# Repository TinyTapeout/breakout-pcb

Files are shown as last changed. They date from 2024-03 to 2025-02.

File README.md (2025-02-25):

# Tiny Tapeout breakout PCBs

The Tiny Tapeout chips are delivered on a breakout board that allows:
   
   * the demo board to host and interact with the IC and its projects
   
   * easily moving the ASIC to other more specialized PCBs

The PCBs are keyed such that direction of insertion onto hosts is made clear.

## Repo organization 

Versionning has been refactored such that we only have a single directory, moving forward, which will always be the latest iteration of the breakout board.  Prior versions are tagged and [all available here](https://github.com/TinyTapeout/breakout-pcb/tags).

To facilitate referencing prior boards, renders and schematic PDFs are archived in [docs/historic](docs/historic), and displayed here.

Additionally, there are directories dedicated to socket adapters and "ASIC simulator" FPGA boards.

## TT08 QFN breakout

The [breakout-tt08-qfn](https://github.com/TinyTapeout/breakout-pcb/releases/tag/breakout-tt08) is a QFN breakout suitable for TT06 chips and beyond.  

The ipex/u.fl connectors used for TT06/TT07 were deemed difficult to use for some and led to relatively high capacitance.  This iteration of the breakout replaces these with standard 100mil headers.

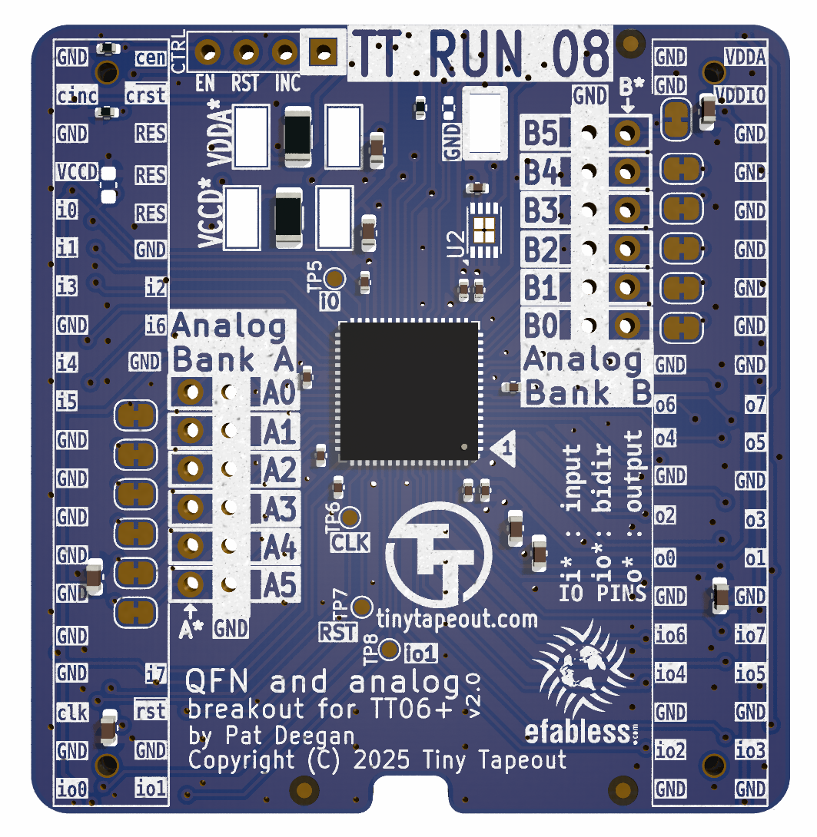
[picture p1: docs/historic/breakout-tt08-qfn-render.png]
TT08 QFN


Each bank of the analog I/O is available through one such connector and also routed to the headers down to the demoboard, but only in order to allow for

  * custom host boards to access these I/O
  
  * pull-downs to ground to avoid floating pins.

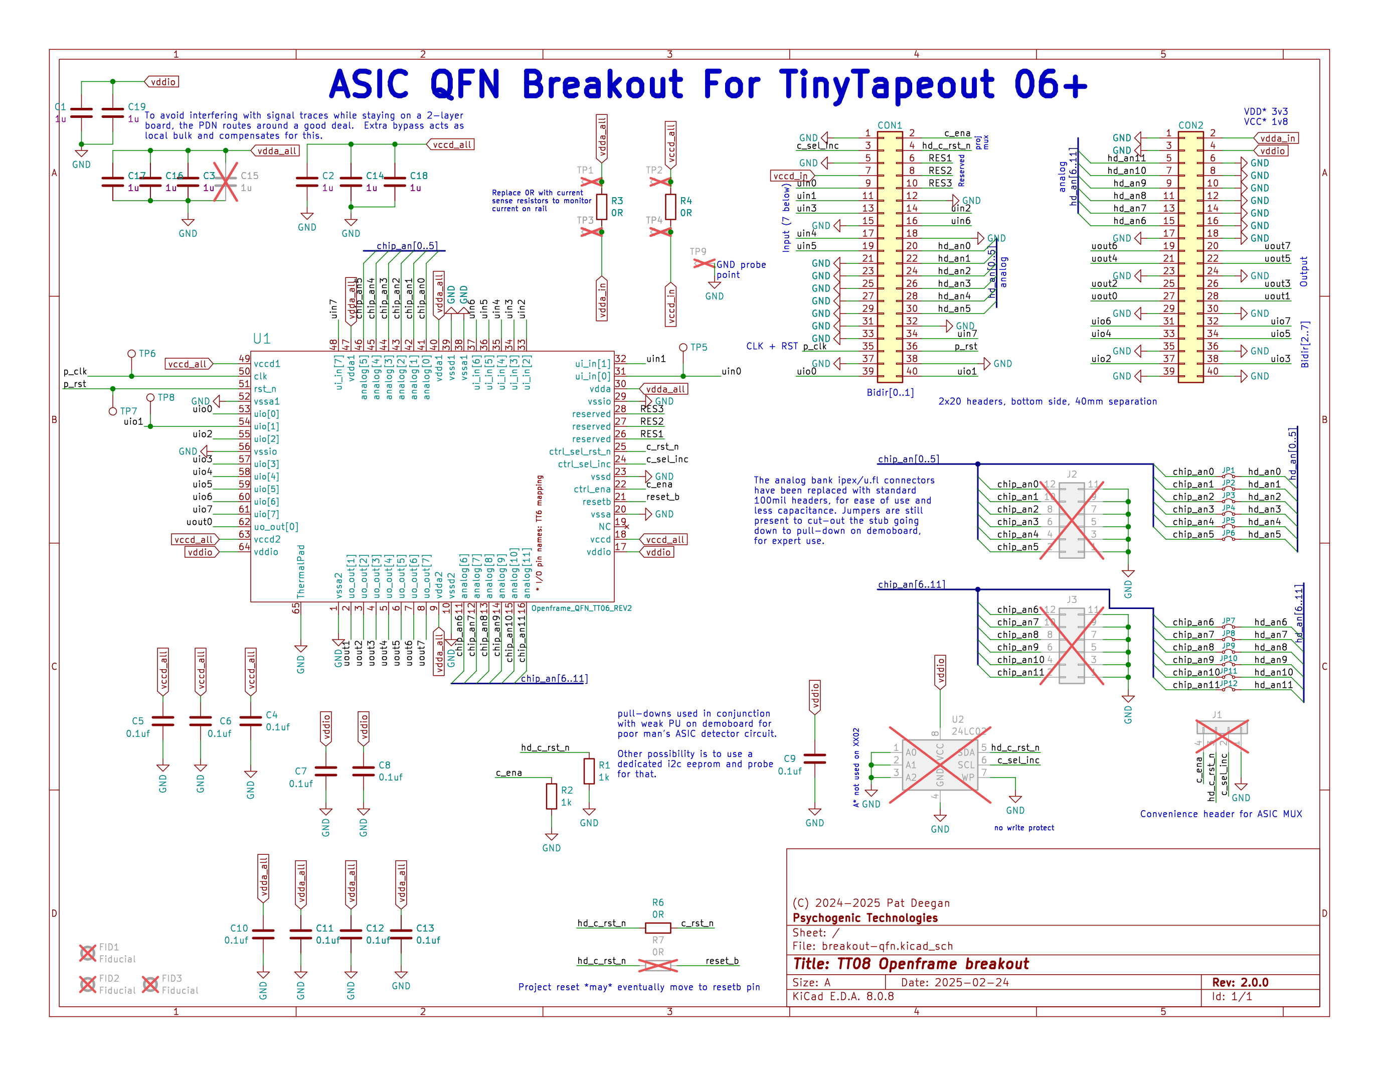
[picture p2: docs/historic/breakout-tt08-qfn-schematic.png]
TT08 breakout schematic


[TT08 breakout schematic PDF](docs/historic/breakout-tt08-qfn.pdf)

## TT07 QFN breakout

The [breakout-tt07-qfn](https://github.com/TinyTapeout/breakout-pcb/releases/tag/breakout-tt07) is a QFN breakout suitable for TT06 chips and beyond.  It was to have only minor changes as compared to the TT06 breakout PCB but, unfortunately, has the ASIC project MUX `reset_n` and `increment` wires crossed and is thus mislabelled.  

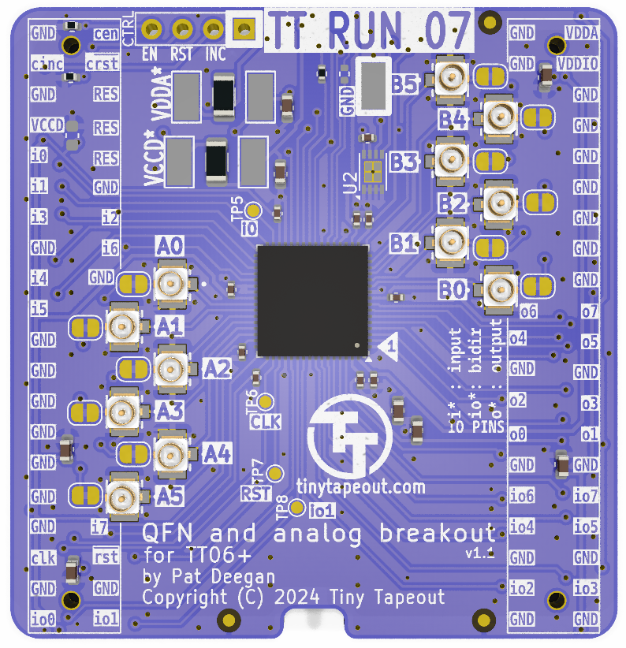
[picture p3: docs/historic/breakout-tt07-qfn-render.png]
TT07 QFN


Analog I/O is available through ipex/u.fl connectors and also routed to the headers and down to the demoboard, but only in order to allow for

  * custom host boards to access these I/O
  
  * pull-downs to ground to avoid floating pins.

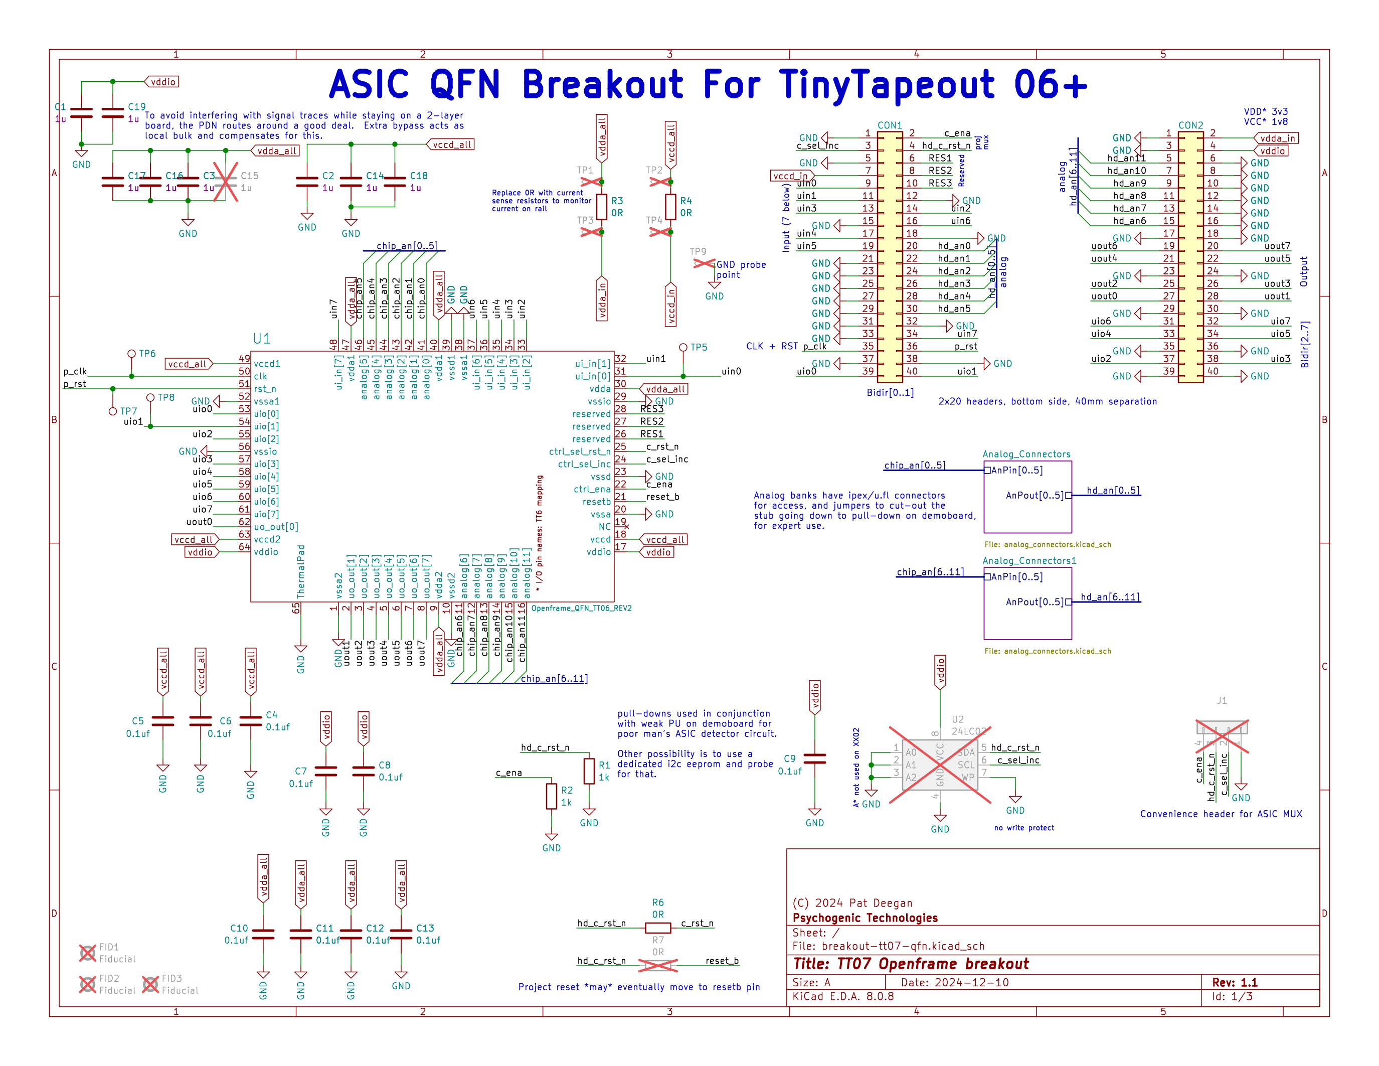
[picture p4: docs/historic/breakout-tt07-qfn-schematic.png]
TT07 breakout schematic


[TT07 breakout schematic PDF](docs/historic/breakout-tt07-qfn.pdf)

## TT06 QFN breakout

The [breakout-tt06-qfn](https://github.com/TinyTapeout/breakout-pcb/releases/tag/breakout-tt06) is a QFN breakout suitable for TT06 chips and beyond.  With TT06 came support for analog and mixed signal projects, as well as a new pinout for the QFN to support this and the on-board project MUX.  These breaking changes are reflected in a new, wider, footprint that sidesteps the possibility of placing incompatible prior breakouts on the demoboard.

Sensitive analog I/O is available through ipex/u.fl connectors.

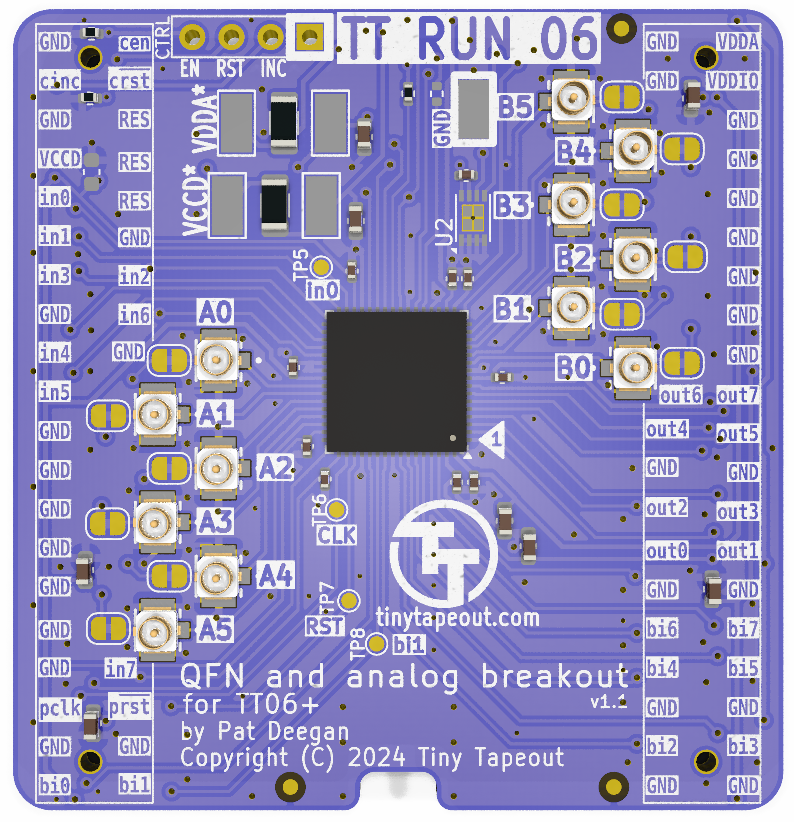
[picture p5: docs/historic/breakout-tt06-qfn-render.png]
TT06 QFN


The analog I/O is also routed to the headers and down to the demoboard, but only in order to allow for

  * custom host boards to access these I/O
  
  * pull-downs to ground to avoid floating pins.
  
Unfortunately, the production run for those demo boards had very low valued resistances which, if you wish to interact with analog projects, had to be removed or replaced (see the errata on the [demoboard documentation](https://github.com/TinyTapeout/tt-demo-pcb/tree/tt06) for details).

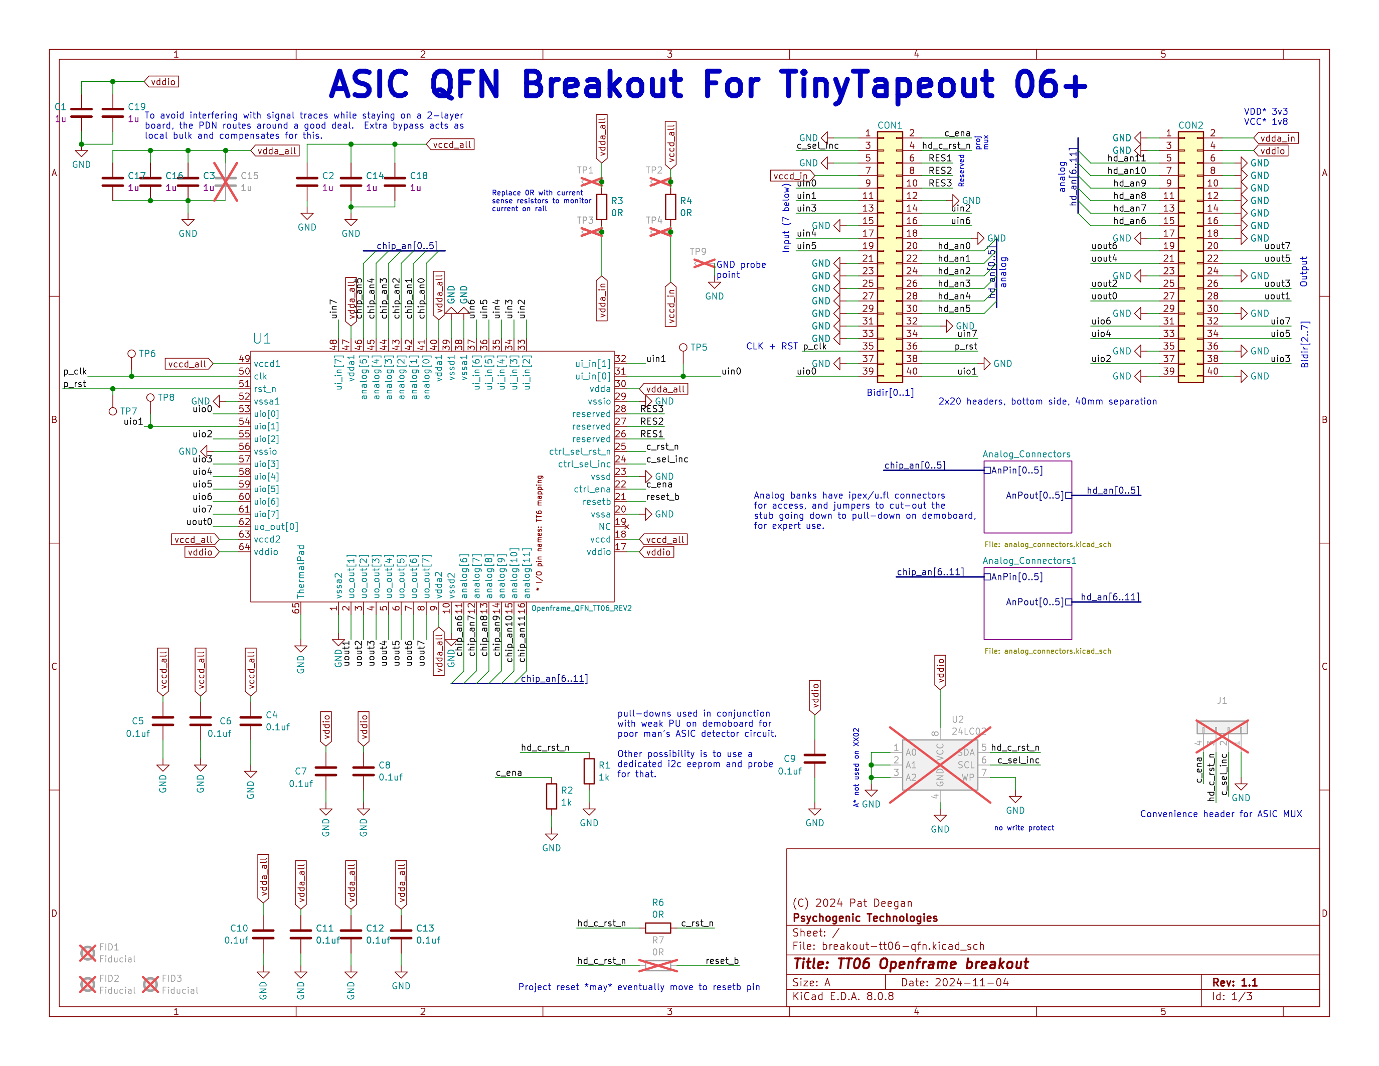
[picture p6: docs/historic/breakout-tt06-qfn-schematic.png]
TT06 breakout schematic


[TT06 breakout schematic PDF](docs/historic/breakout-tt06-qfn.pdf)

## TT04/TT05 QFN breakout

The [breakout-tt04-qfn](https://github.com/TinyTapeout/breakout-pcb/releases/tag/breakout-tt04) is a QFN breakout suitable for TT04 and TT05 chips.  This breakout, with some differences in silk screen, was used for the TT03p5 trial run, as well as TT04 and TT05.

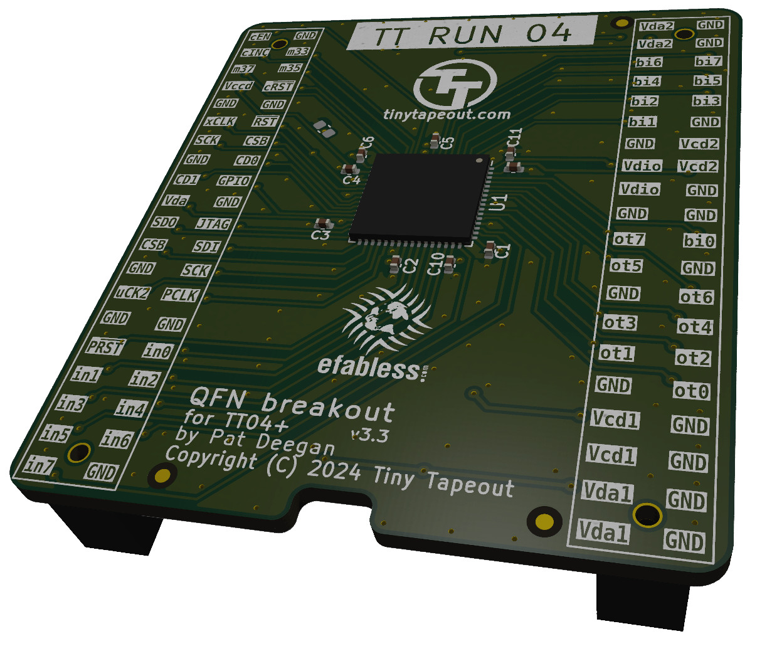
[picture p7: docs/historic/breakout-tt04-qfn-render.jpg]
TT04 QFN


This PCB moved to more easily sourced standard 100 mil pin headers, placed on the bottom of the PCB.  Markings on top are Tiny Tapeout names of the pins (in0 is input 0, ot5 is output 5, etc).

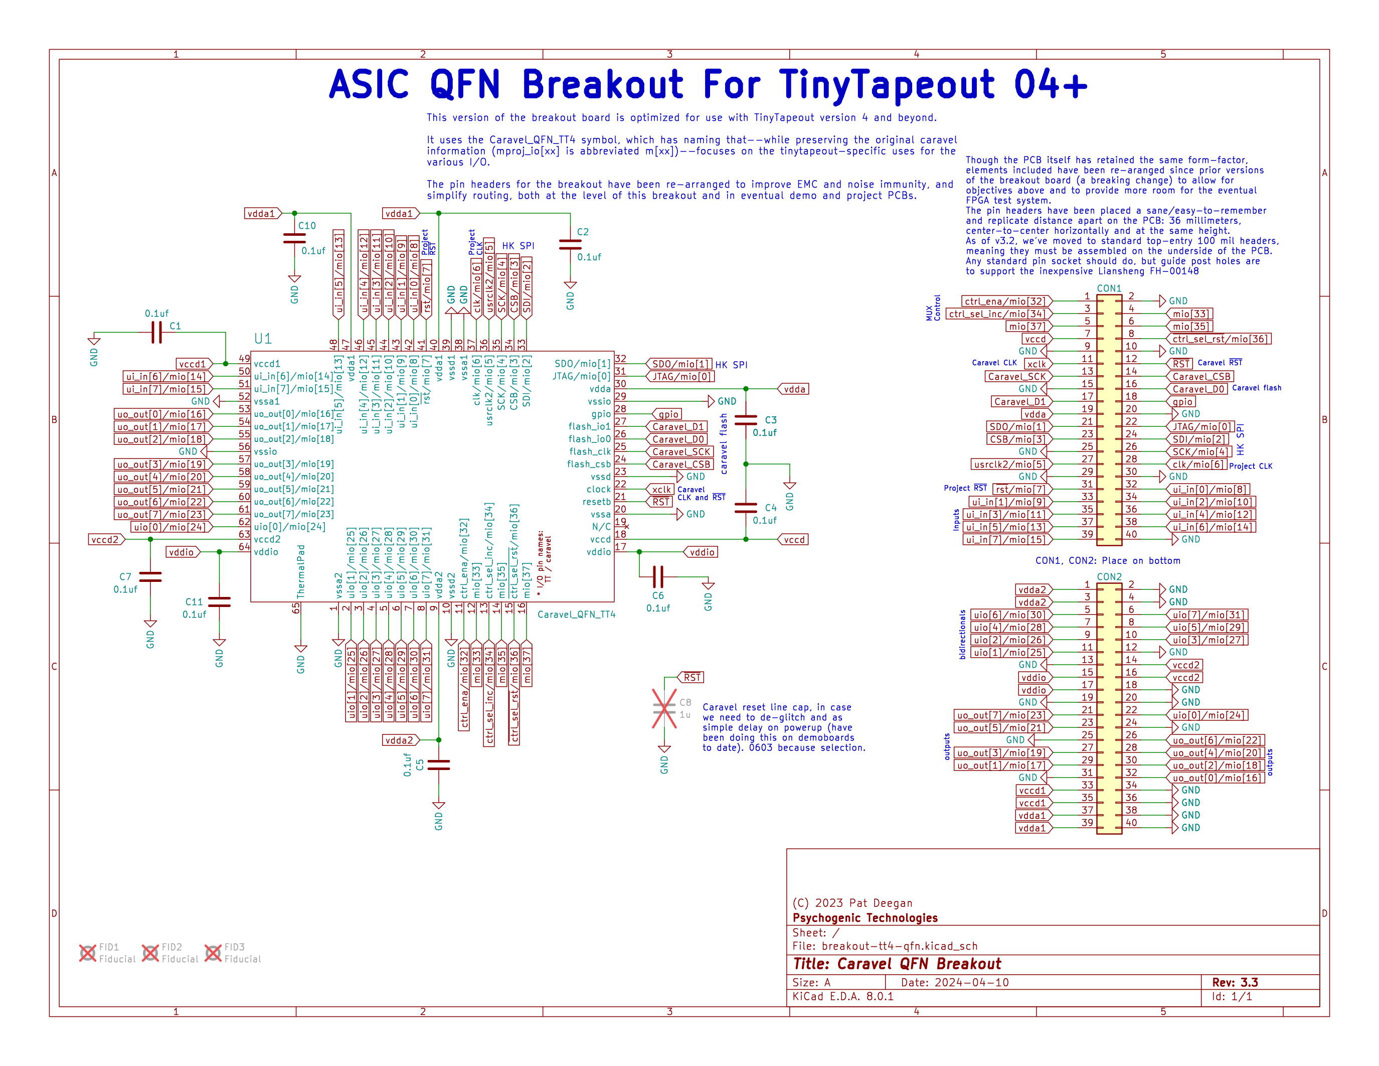
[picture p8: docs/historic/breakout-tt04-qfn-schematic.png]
TT04 breakout schematic


[TT04 breakout schematic PDF](docs/historic/breakout-tt04-qfn.pdf)

## TT03 QFN breakout

The [breakout-tt03-qfn](https://github.com/TinyTapeout/breakout-pcb/releases/tag/breakout-tt03) holds a QFN breakout suitable for TT02 and TT03 chips.

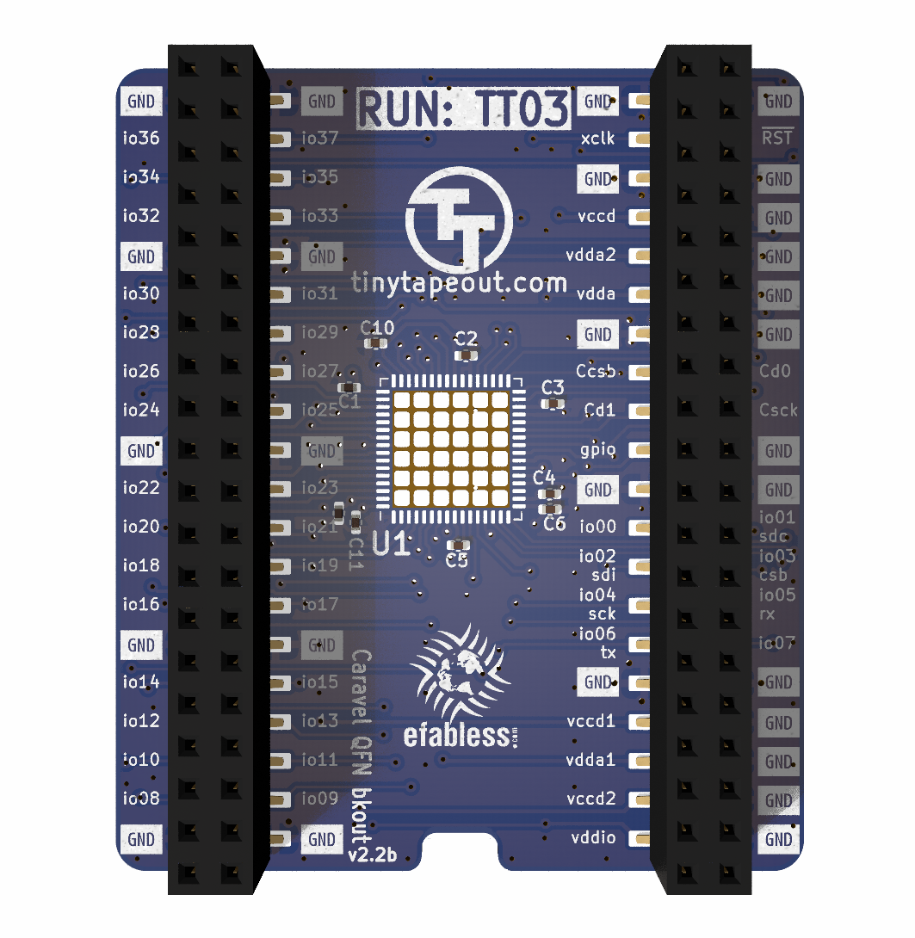
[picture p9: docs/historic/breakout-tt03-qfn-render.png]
TT03 QFN


It provides access to the project inputs, outputs, select pins etc, though the naming on the PCB refers to the caravel mprj_io pin numbers.

The pin headers used up to this point have been dual entry (access from both top and bottom).

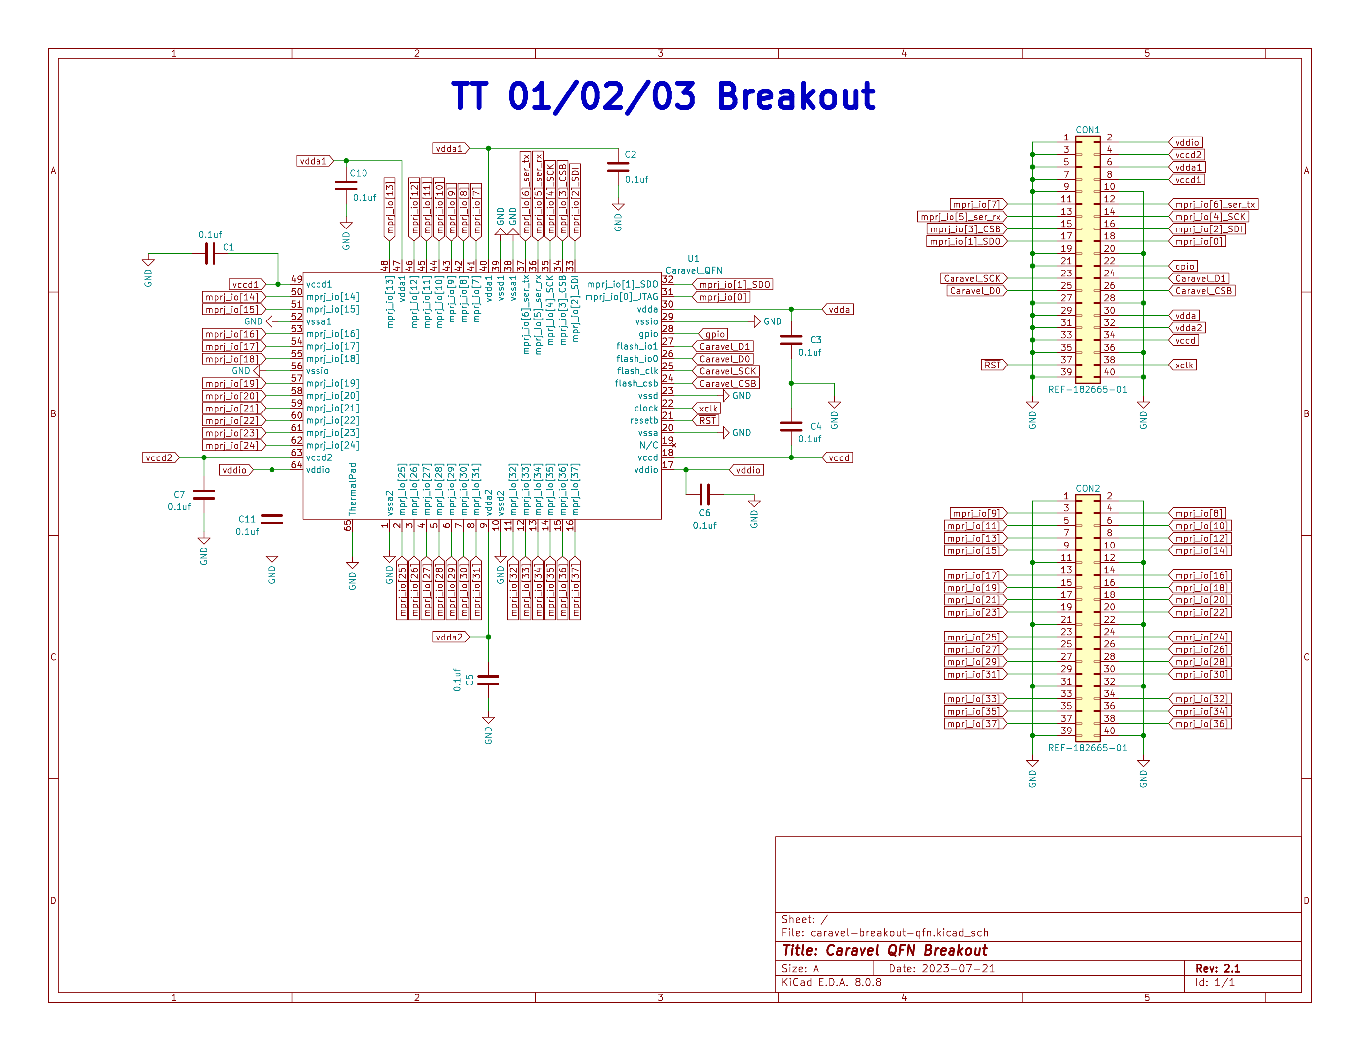
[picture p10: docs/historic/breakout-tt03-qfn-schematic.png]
TT03 breakout schematic


[TT03 breakout schematic PDF](docs/historic/breakout-tt03-qfn.pdf)

## FPGA ASIC simulation PCBs

Following the same footprints as the breakout boards, the ASIC simulation PCBs are circuits designed to allow for use of demo or custom boards while developing or awaiting the actual chips.  A version was already produced for TT03 and a TT04-compatible version, with the extra I/O and dedicated clock/reset pins, is under development.

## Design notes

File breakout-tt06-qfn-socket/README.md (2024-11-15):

# Tiny Tapeout QFN64 socket adapter (TT06+)

For testing Tiny Tapeout chips not yet soldered to a breakout board.<br />
Based on the [TT06 QFN breakout board](https://github.com/TinyTapeout/breakout-pcb) by Pat Deegan.

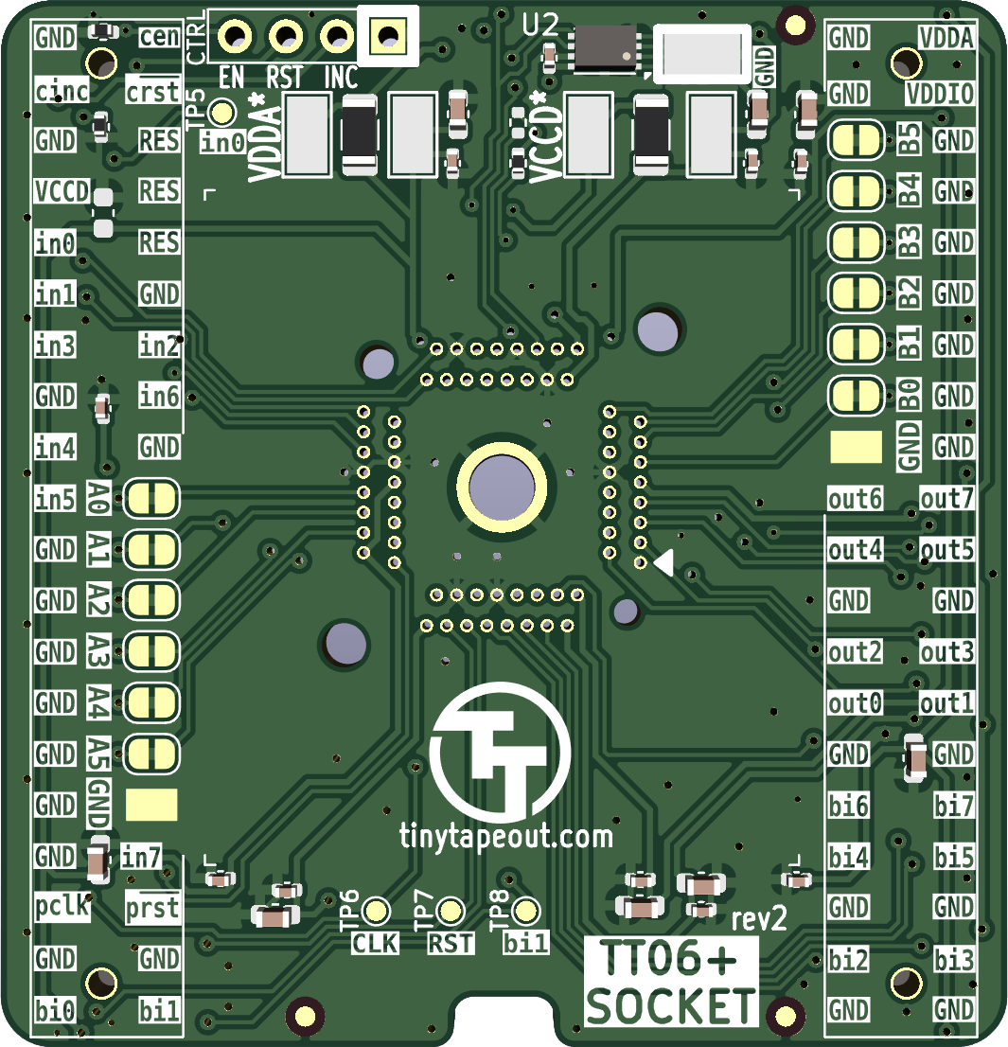
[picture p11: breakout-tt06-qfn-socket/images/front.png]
&emsp;
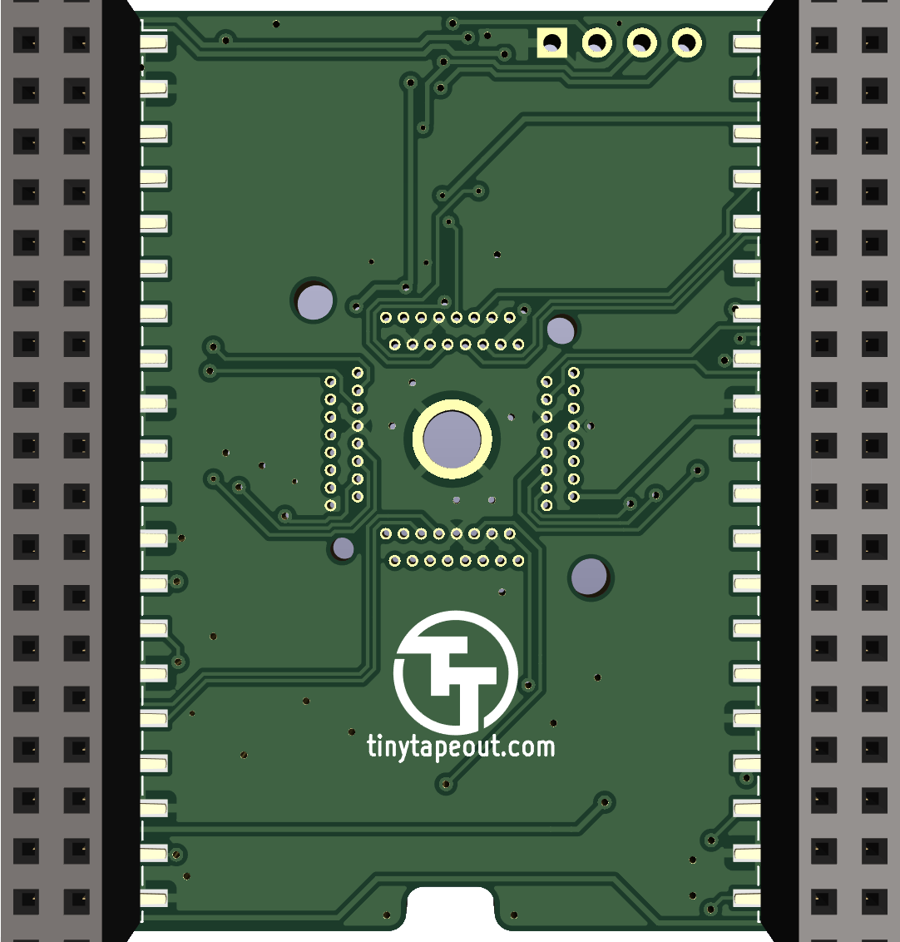
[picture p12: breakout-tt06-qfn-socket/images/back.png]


To be used with [Enplas QFN-64BT-0.5-01](https://www.waveshare.com/qfn-64bt-0.5-01.htm) sockets.

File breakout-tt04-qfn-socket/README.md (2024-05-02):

# Tiny Tapeout QFN64 socket adapter (TT04+)

For testing Tiny Tapeout chips not yet soldered to a breakout board.<br />
Based on the [TT04 QFN breakout board](https://github.com/TinyTapeout/breakout-pcb) by Pat Deegan.

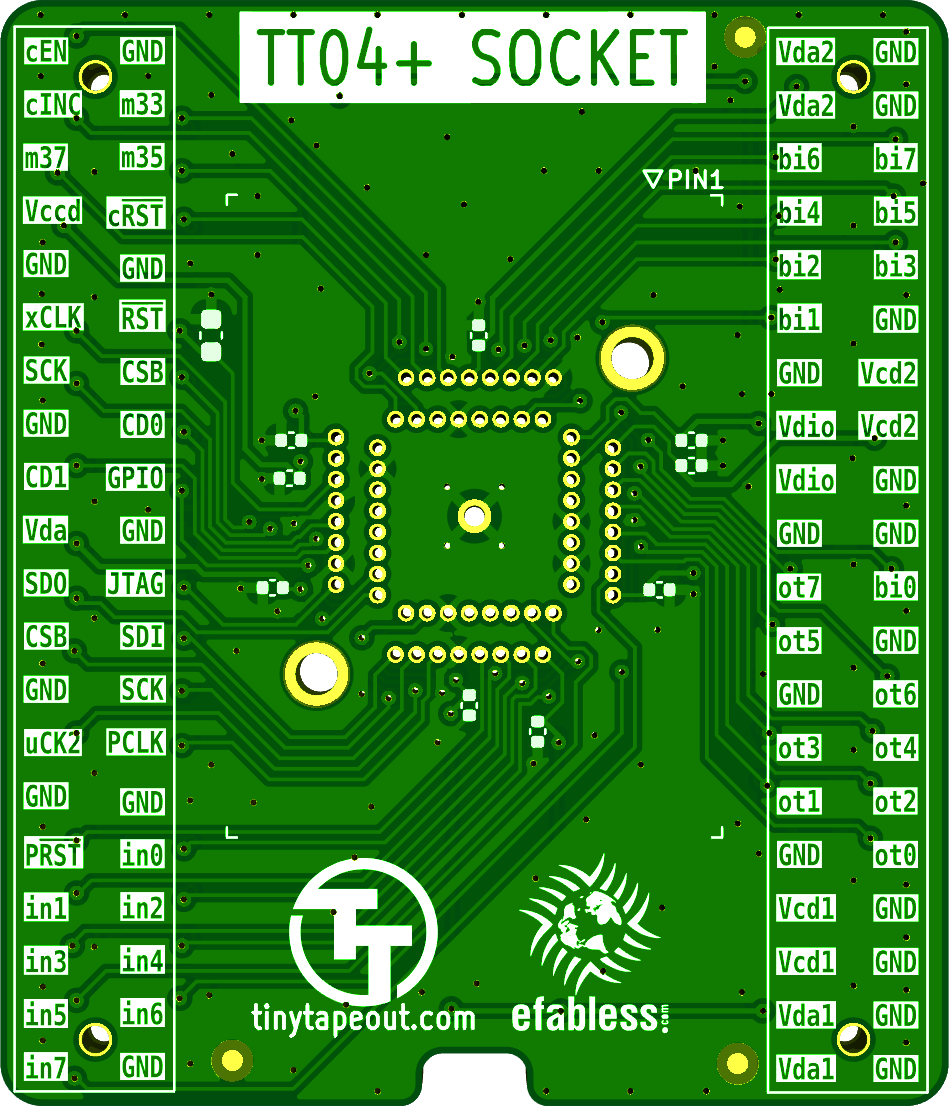
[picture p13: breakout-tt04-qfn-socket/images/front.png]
&emsp;
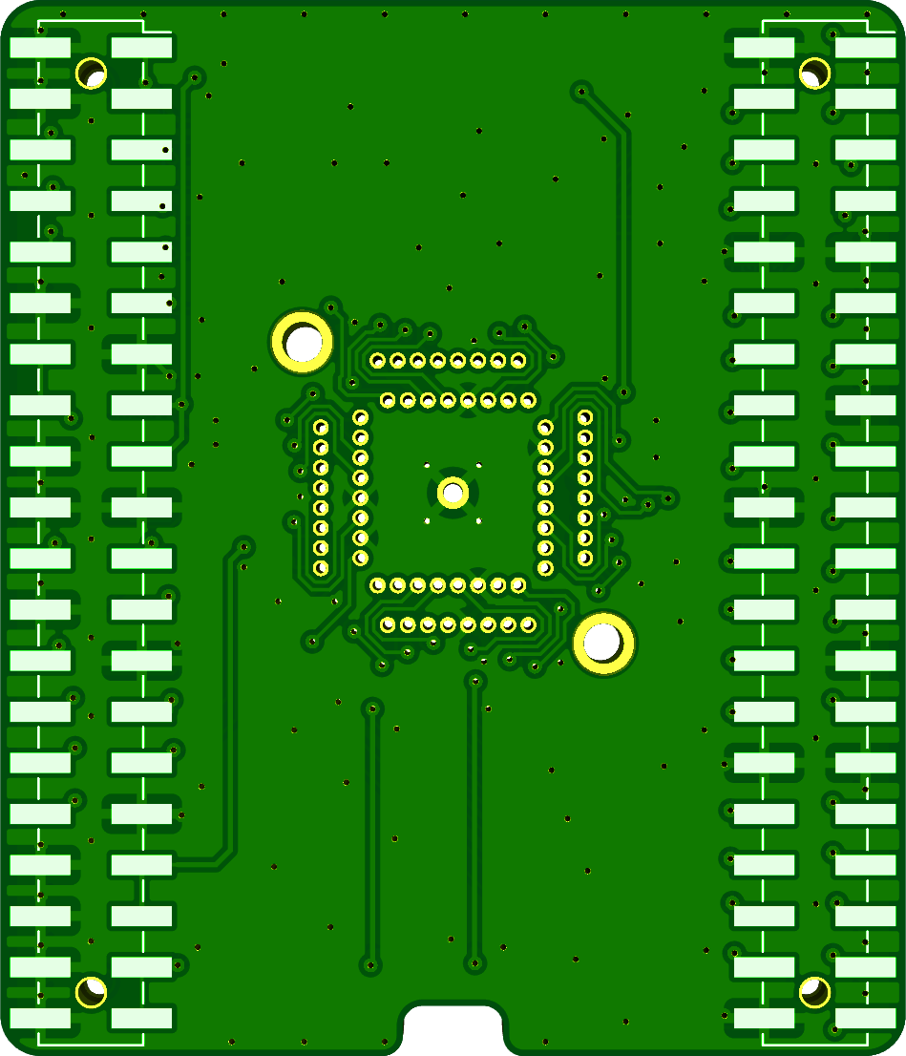
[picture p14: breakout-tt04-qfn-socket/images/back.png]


To be used with Chinese 9x9-64-0.5 QFN sockets, such as those available with these vendors:
[#1](https://www.aliexpress.com/item/1005005700155525.html) /
[#2](https://www.taobao.com/list/item/708110757161.htm) /
[#3](https://www.taobao.com/list/item/736773077075.htm)

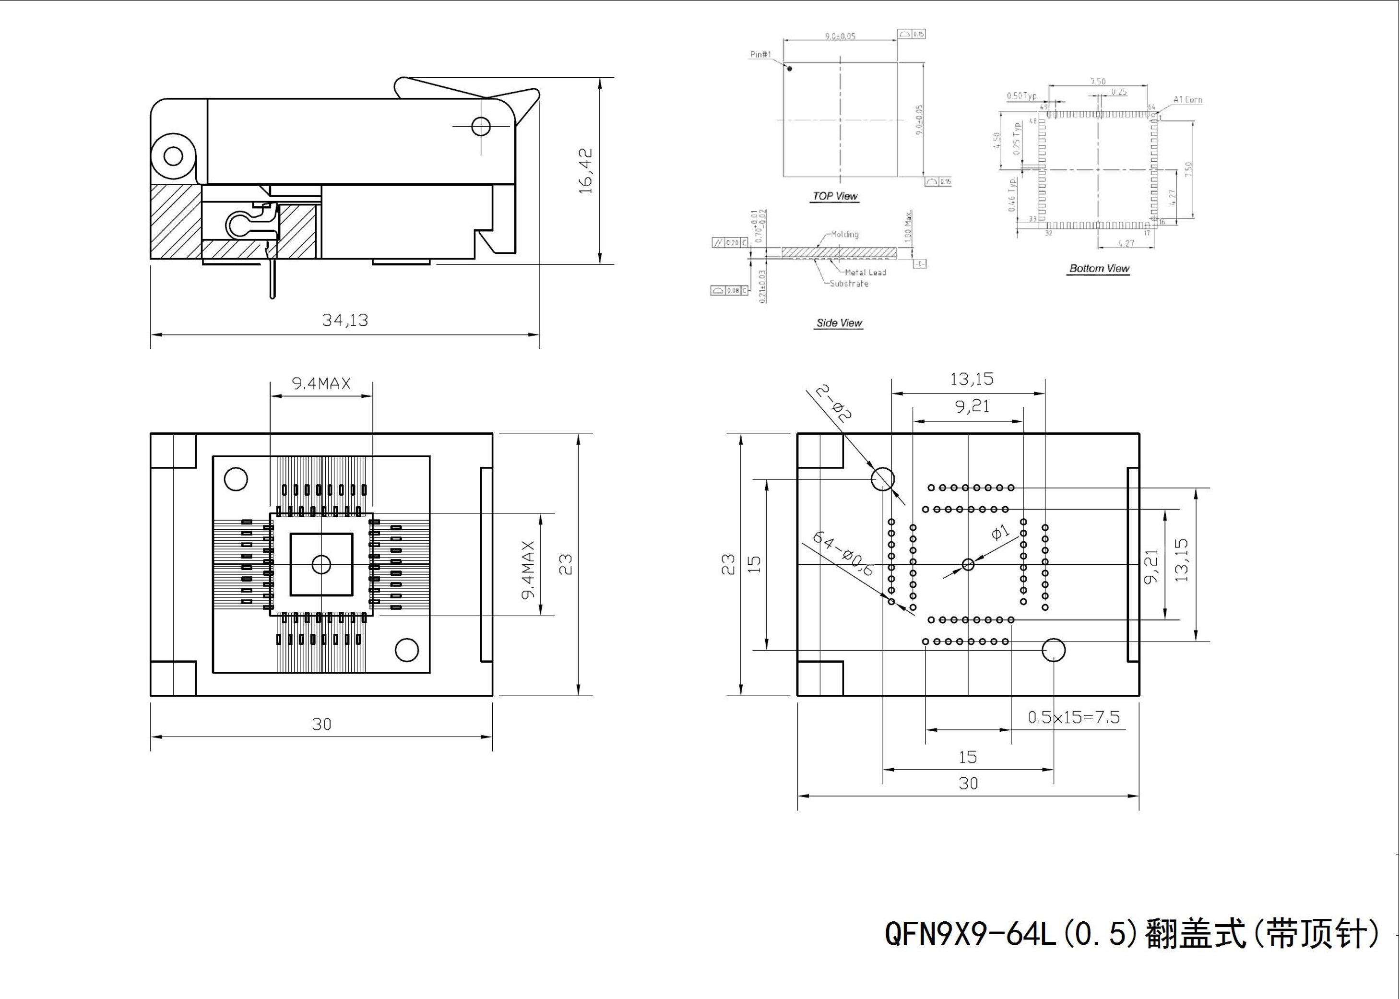
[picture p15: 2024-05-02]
breakout-tt04-qfn-socket/images/footprint.jpg

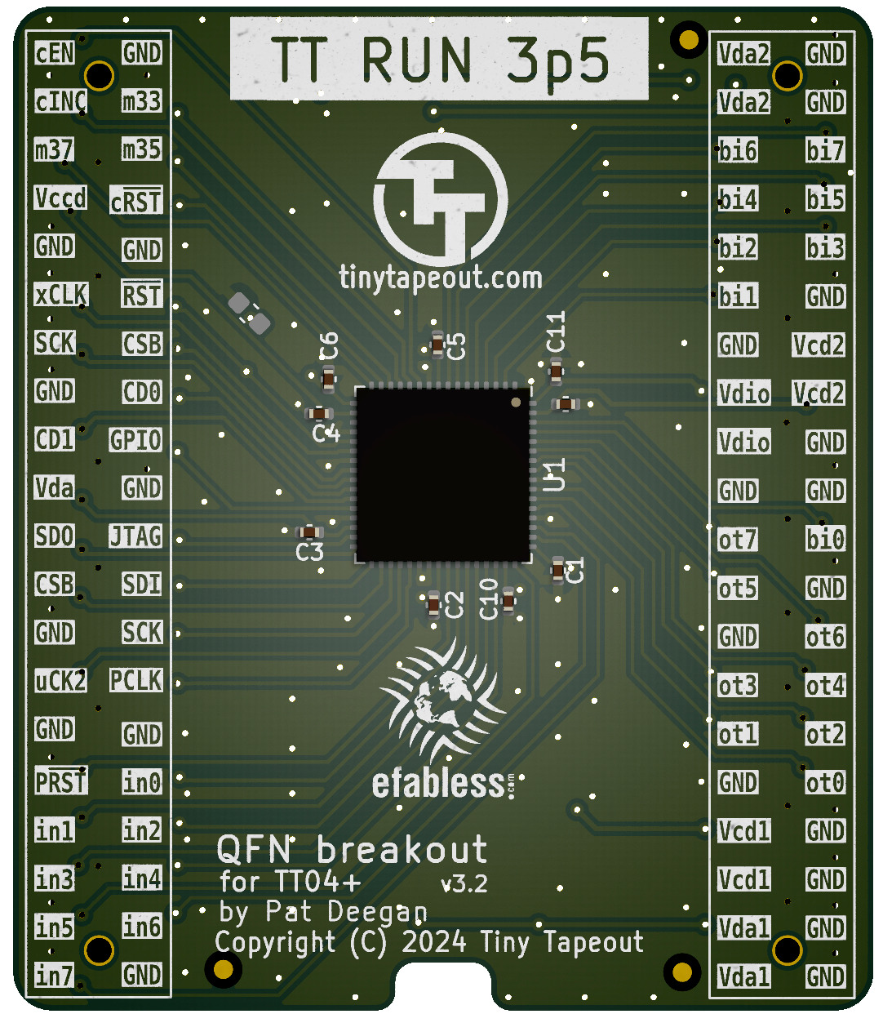
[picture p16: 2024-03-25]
images/tt04-breakout.jpg

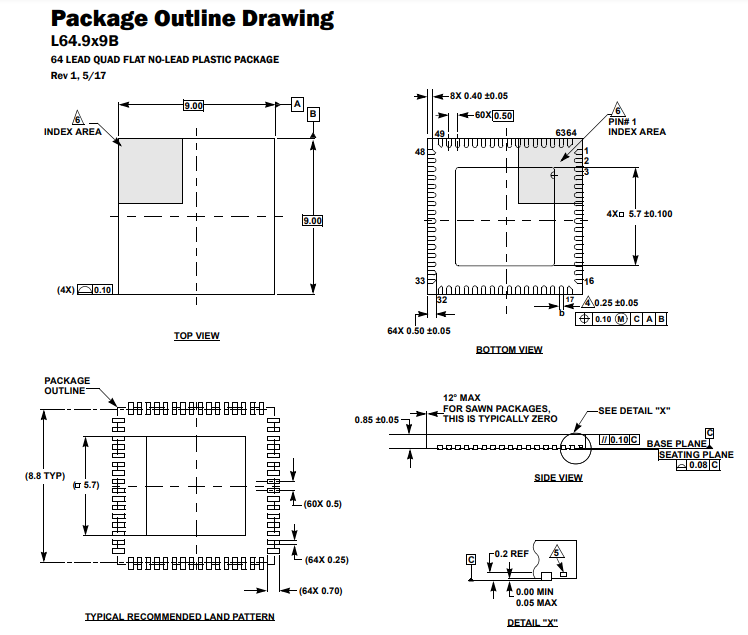
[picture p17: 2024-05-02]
breakout-tt04-qfn-socket/images/package.jpg

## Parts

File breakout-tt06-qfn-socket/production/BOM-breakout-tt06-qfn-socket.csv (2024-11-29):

Comment | Designator | Footprint | LCSC | Quantity
1k | R1,R2 | R_0402_1005Metric | C11702 | 2
0.1u | C10,C11,C12,C13,C4,C5,C6,C7,C8,C9 | C_0402_1005Metric | C1525 | 10
1u | C1,C14,C15,C16,C17,C18,C19,C2,C3 | C_0603_1608Metric | C15849 | 9
0R | R6 | R_0402_1005Metric | C17168 | 1
0R | R3,R4 | R_1206_3216Metric | C17888 | 2
~ | CON1,CON2 | FH-00148_PinSocket_2x20_P2.54mm | C2685092 | 2
TestPoint_Alt | TP1,TP2,TP3,TP4,TP9 | TestPoint_Keystone_5019_Minature | C5199800 | 5
Enplas QFN-64BT-0.5-01 | U1 | Socket-QFN-64-1EP_9x9mm_P0.5mm_rot90 |  | 1

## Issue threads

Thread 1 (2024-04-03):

Link at the back of tt04 PCB sends you to the old repo

urish, 2024-04-03:
It reads: github.com/TinyTapeout/caravel-breakout-pcb
Should be: github.com/TinyTapeout/breakout-pcb (this repo)

psychogenic, 2024-04-11:
Created new v3.3 release of TT04 carriers, updated silk with this fix.

Closed 2024-04-11.

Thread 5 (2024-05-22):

make the pin 1 marker much more obvious

mattvenn, 2024-05-22:

urish, 2024-05-22:
Is this for TT05? or later

mattvenn, 2024-05-22:
All boards in use and in future. A tiny dot or similar isn't clear enough

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

urish, 2024-05-22:
@psychogenic can you make this change and include it in the gerber files for TT05 carrier boards?

psychogenic, 2024-06-04:
Gave it le fat arrow, think it'll be plenty clear
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

urish, 2024-06-04:
Thanks! maybe even write "1" or "Pin 1" on top, to be super duper clear?

psychogenic, 2024-06-04:
Is it worth it?  Feels like anyone doing PCBA with a QFN can probably handle the hint.  But I'll do it if ya like.

psychogenic, 2024-06-04:
Ok, this would be hard to miss then
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

urish, 2024-06-05:
Beauty!

Closed 2024-06-05.

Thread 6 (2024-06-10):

make pin1 marker for the black qfn breakout

mattvenn, 2024-06-10:
Proppy in the discord just soldered it the wrong way round.

urish, 2024-06-10:
Similar to #5

mattvenn, 2024-06-11:
yeah. all boards should have a massive pin 1 marker

psychogenic, 2024-06-11:
Done and will do for future, sent to the Stu
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

Closed 2024-06-11.

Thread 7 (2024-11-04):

TT06 breakout: c_sel_inc and c_rst_n pins swapped

urish, 2024-11-04:
There's an error in the schematic - the pins are swapped:

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

The symbol pinout is correct, but the wire labels are wrong: `c_sel_inc` should be at QFN pin 24, and `c_rst_n` should be at QFN pin 25.

psychogenic, 2024-11-04:
Ok, good catch there.  Uncrossed the streams heading to chip, changed nothing in terms of headers with commit:

https://github.com/TinyTapeout/breakout-pcb/commit/599e5e56a7ecb6514cfa40402f07a592d649720a

urish, 2025-02-18:
Appeared again in TT07, should be fixed for future board revisions.

Closed 2025-02-18.

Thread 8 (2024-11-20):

standardise terminology

mattvenn, 2024-11-20:
we are calling these carrier boards, but the repo and silkscreen says breakout

urish, 2025-02-18:
We've changed terminology - we now call those breakout boards.

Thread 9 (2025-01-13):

Remove solder mask between analog jumper pads

algofoogle, 2025-01-13:
The analog jumper pads have solder mask between them:
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

If this were removed, it would make it more obvious that the pads are bridged, and probably make it a tiny bit easier to cut them (and verify they are cleanly cut).

urish, 2025-02-18:
I guess this is no longer relevant due to #10?

psychogenic, 2025-02-18:
Maybe?  Are we dropping the jumpers/pull-downs on the DB?

urish, 2025-02-18:
We're keeping them, as discussed on discord

psychogenic, 2025-02-25:
done

Closed 2025-02-25.

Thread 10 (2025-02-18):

Replace U.FL with friendlier 100mil headers

psychogenic, 2025-02-18:
The analog pin u.fl have proven difficult to use and high capacitance--we want to replace these with 2x unpopulated 100mil 2x6 headers, one per bank.

psychogenic, 2025-02-25:
done

Closed 2025-02-25.

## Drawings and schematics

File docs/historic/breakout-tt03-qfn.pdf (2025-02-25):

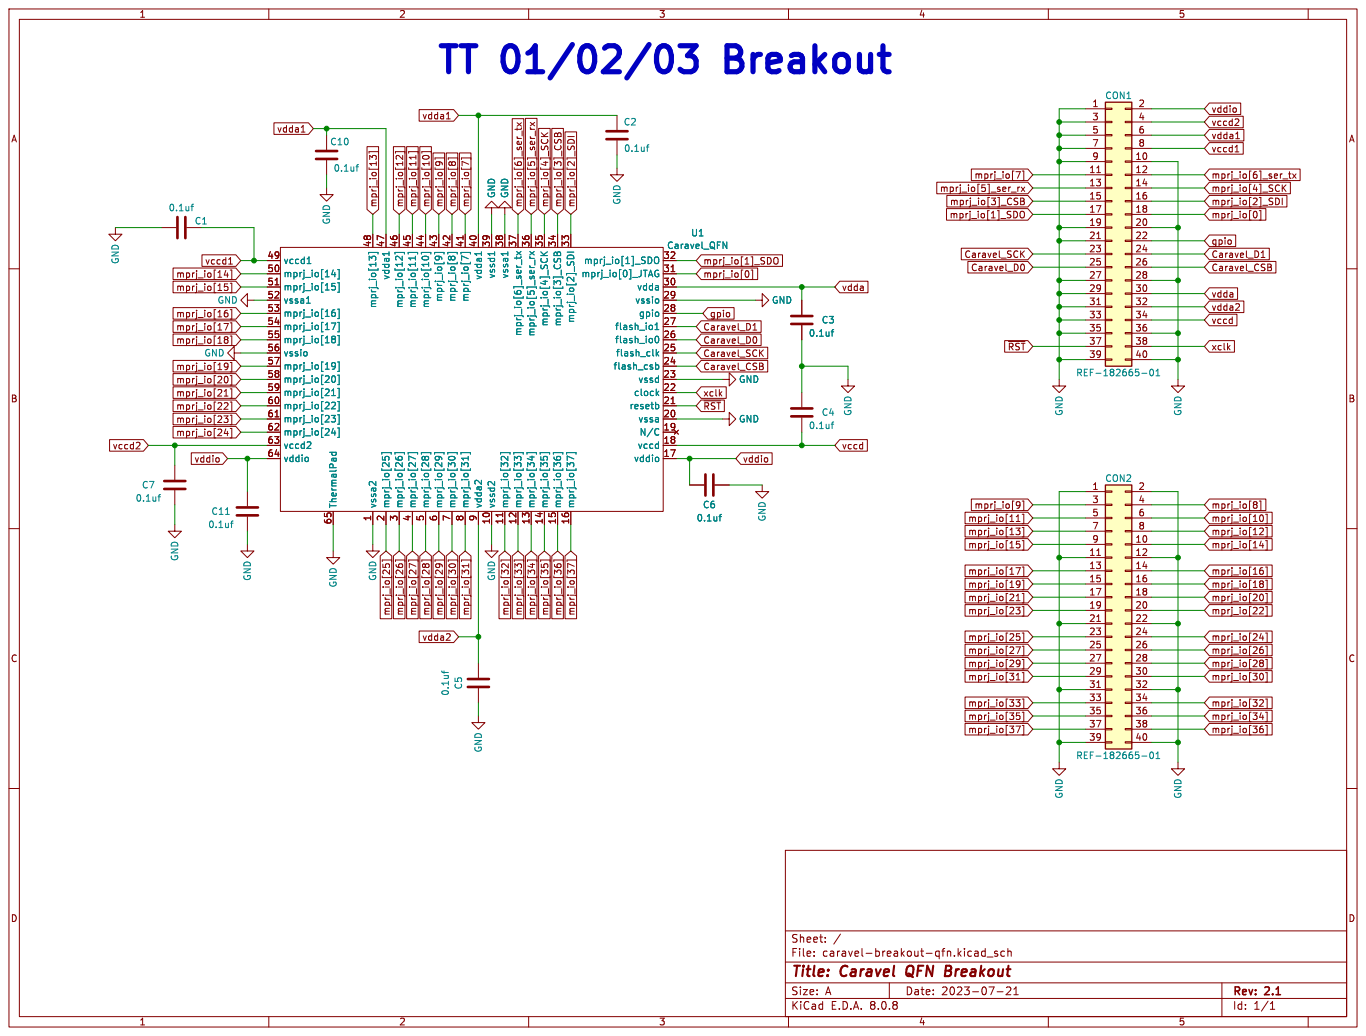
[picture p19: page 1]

Id: 1/1 Title: Caravel QFN Breakout File: caravel-breakout-qfn.kicad_sch Sheet: /

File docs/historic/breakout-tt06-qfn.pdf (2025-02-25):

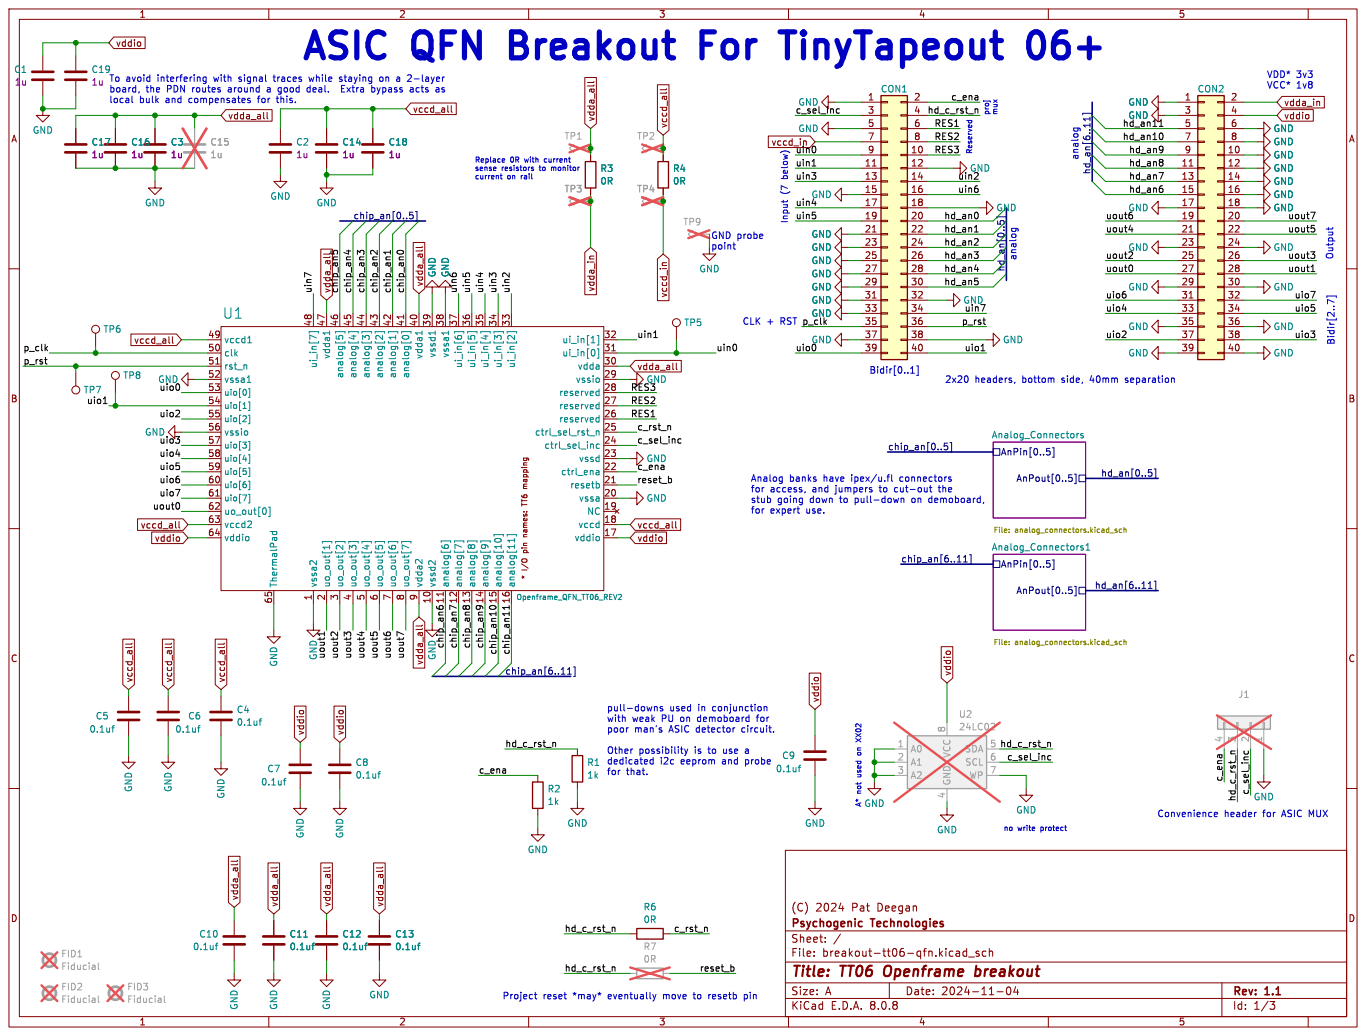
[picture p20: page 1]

ASIC QFN Breakout For TinyTapeout 06+

1 vssd2 10 analog[6] 11 analog[7] 12 analog[8] 13 analog[9] 14 analog[10] 15 analog[11] 16

4 SDA 5 SCL 6 WP 7 VCC

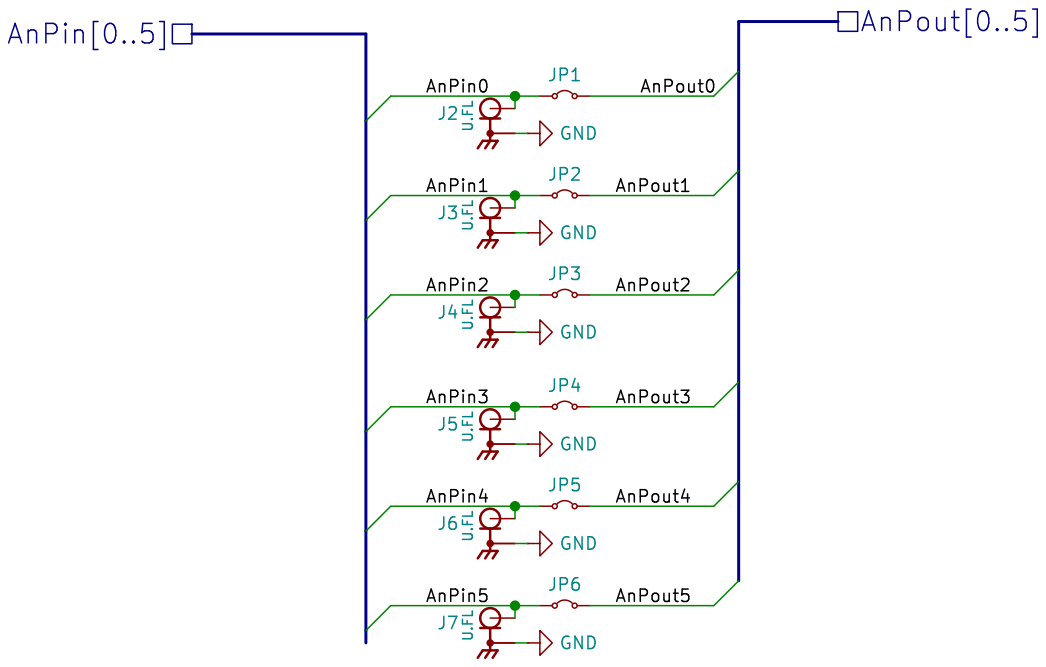
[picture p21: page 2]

Id: 2/3 Title: File: analog_connectors.kicad_sch Sheet: /Analog_Connectors/

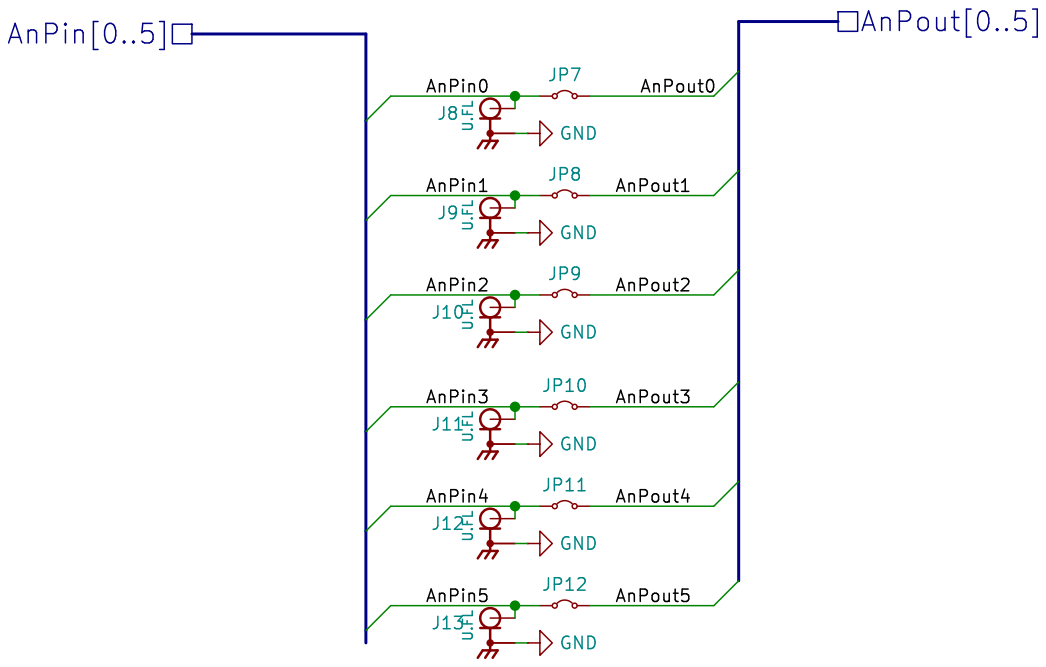
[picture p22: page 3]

Id: 3/3 Title: File: analog_connectors.kicad_sch Sheet: /Analog_Connectors1/

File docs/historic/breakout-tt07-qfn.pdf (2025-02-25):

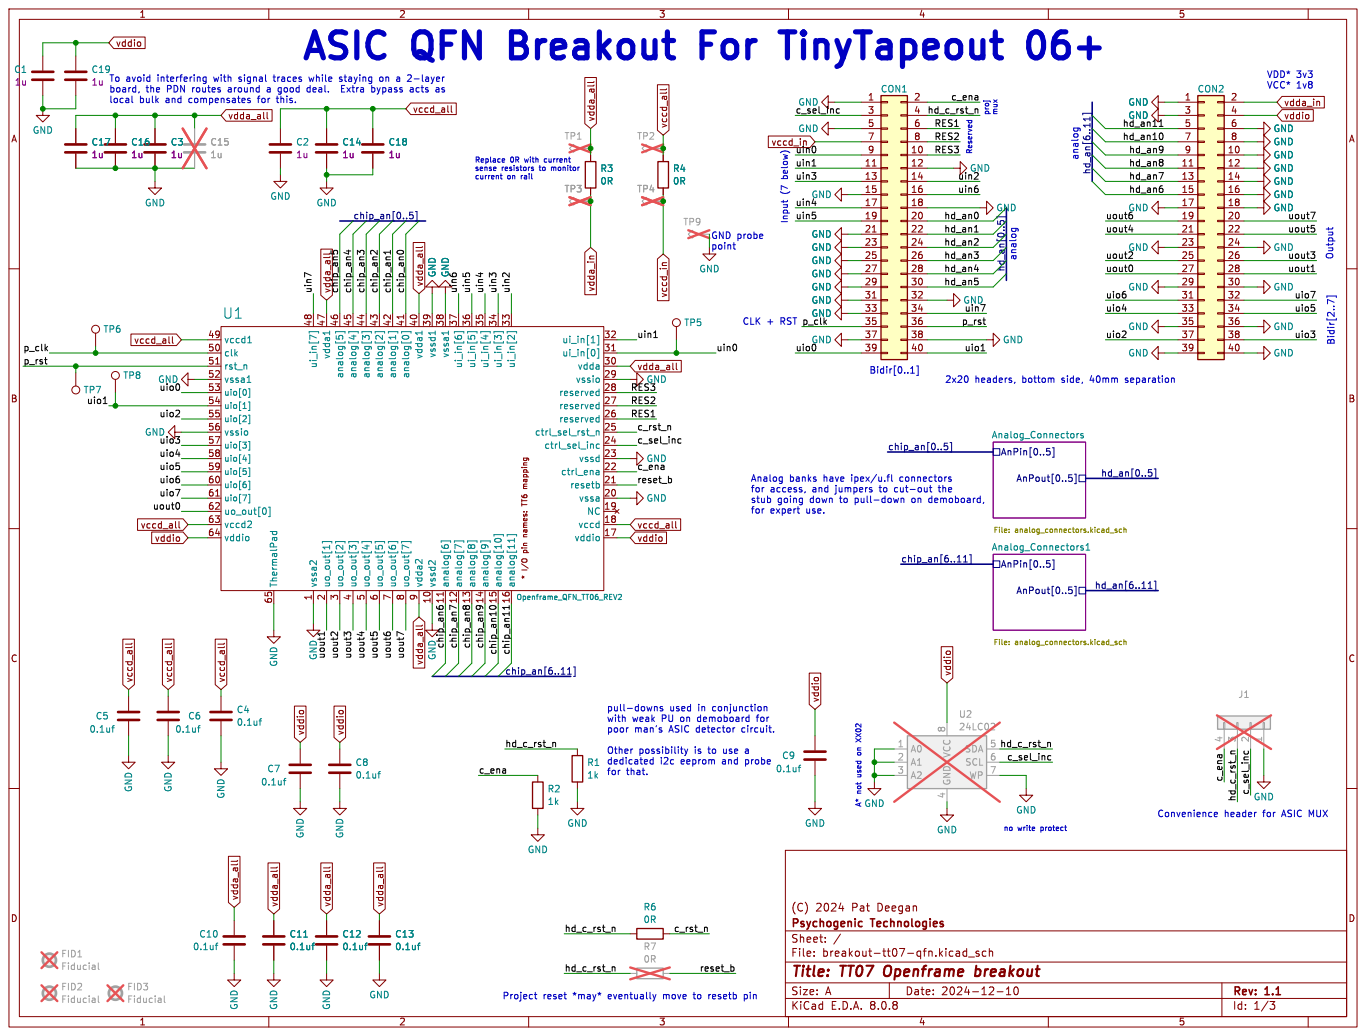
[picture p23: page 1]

ASIC QFN Breakout For TinyTapeout 06+

1 vssd2 10 analog[6] 11 analog[7] 12 analog[8] 13 analog[9] 14 analog[10] 15 analog[11] 16

4 SDA 5 SCL 6 WP 7 VCC

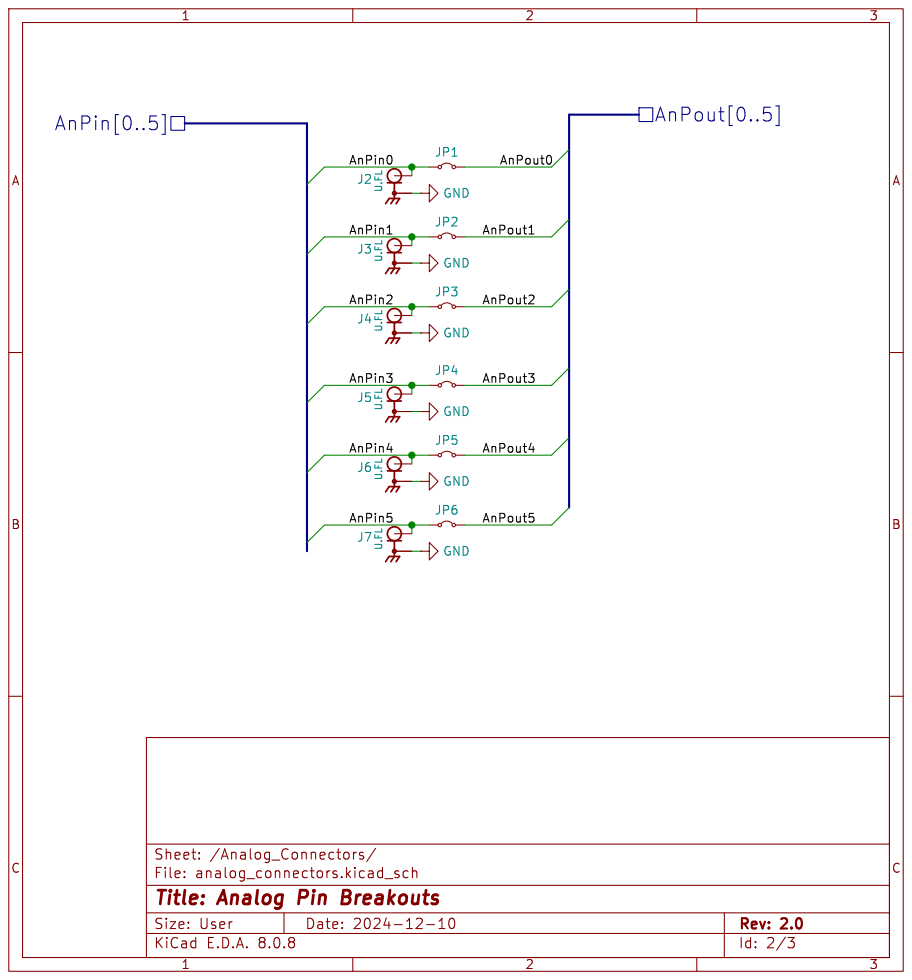
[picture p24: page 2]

Id: 2/3 Title: Analog Pin Breakouts

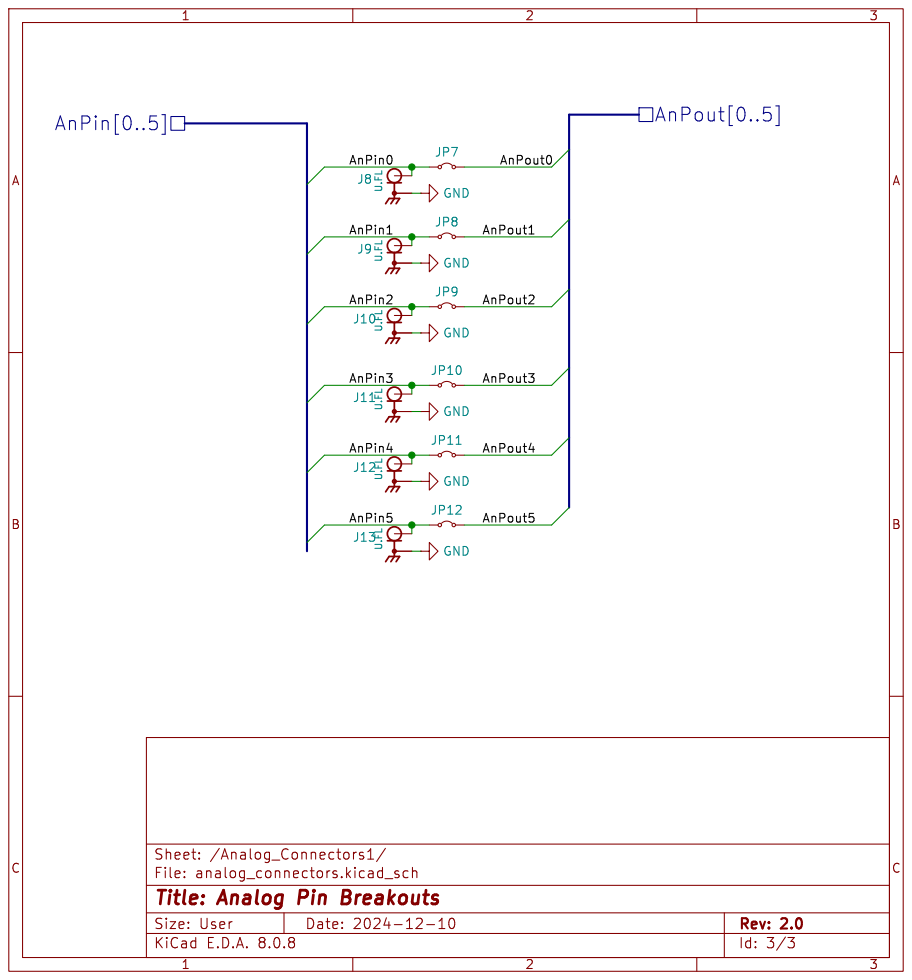
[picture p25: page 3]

Id: 3/3 Title: Analog Pin Breakouts

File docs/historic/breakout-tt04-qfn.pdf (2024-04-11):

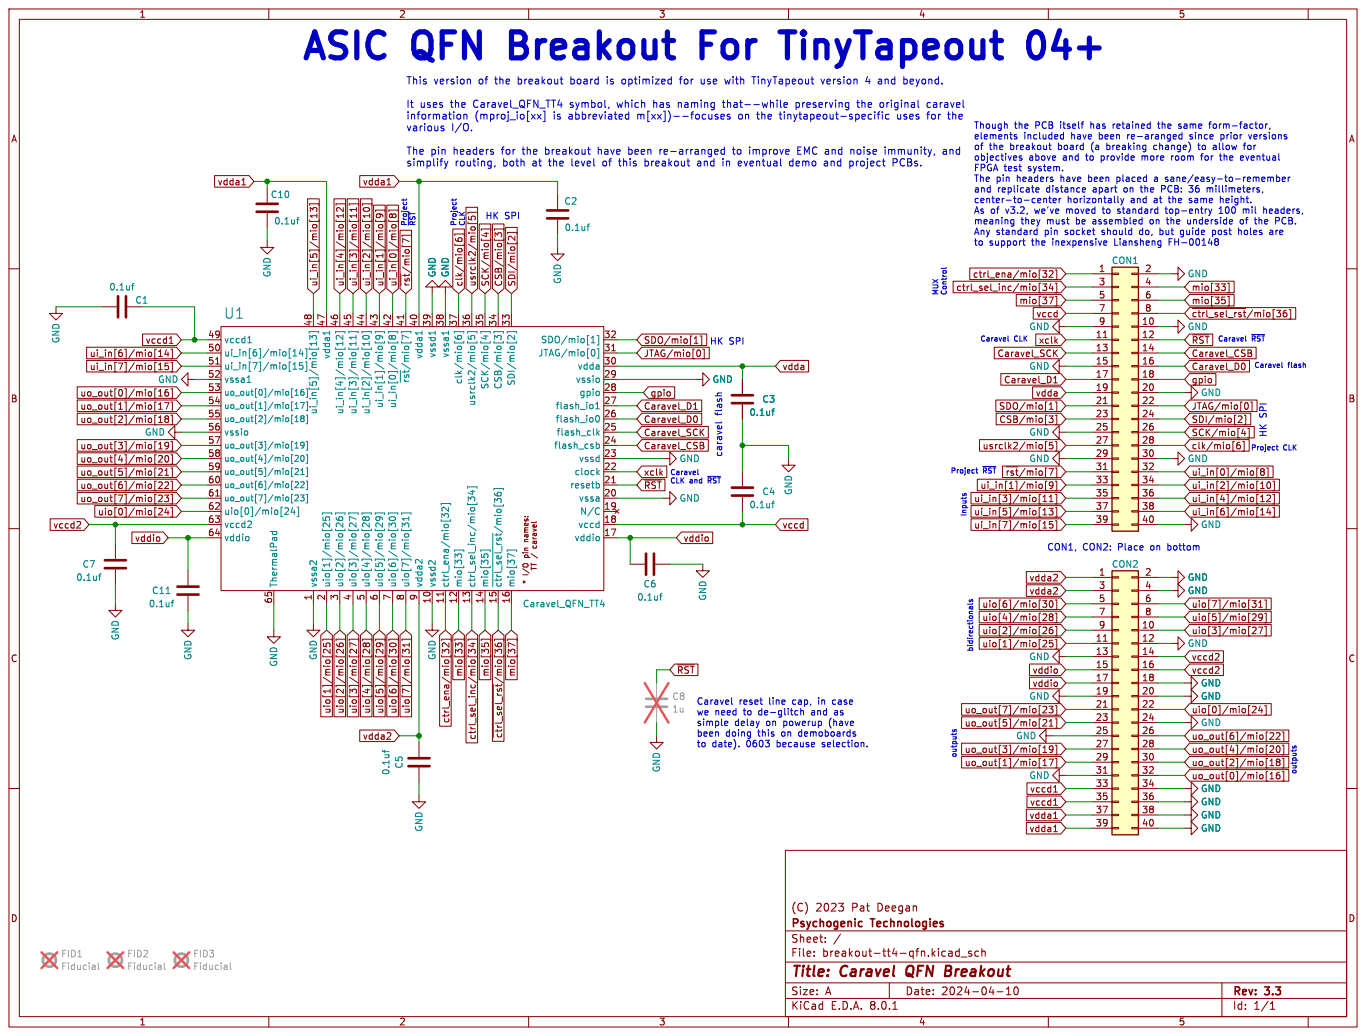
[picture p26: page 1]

~{RST} xclk clk/mio[6]

* I/O pin names: TT / caravel vssa2

1 vssd2 10 ctrl_ena/mio[32] 11 mio[33] 12 ctrl_sel_inc/mio[34] 13 mio[35] 14 ~{ctrl_sel_rst}/mio[36] 15 mio[37] 16

simple delay on powerup (have
been doing this on demoboards
to date). 0603 because selection.

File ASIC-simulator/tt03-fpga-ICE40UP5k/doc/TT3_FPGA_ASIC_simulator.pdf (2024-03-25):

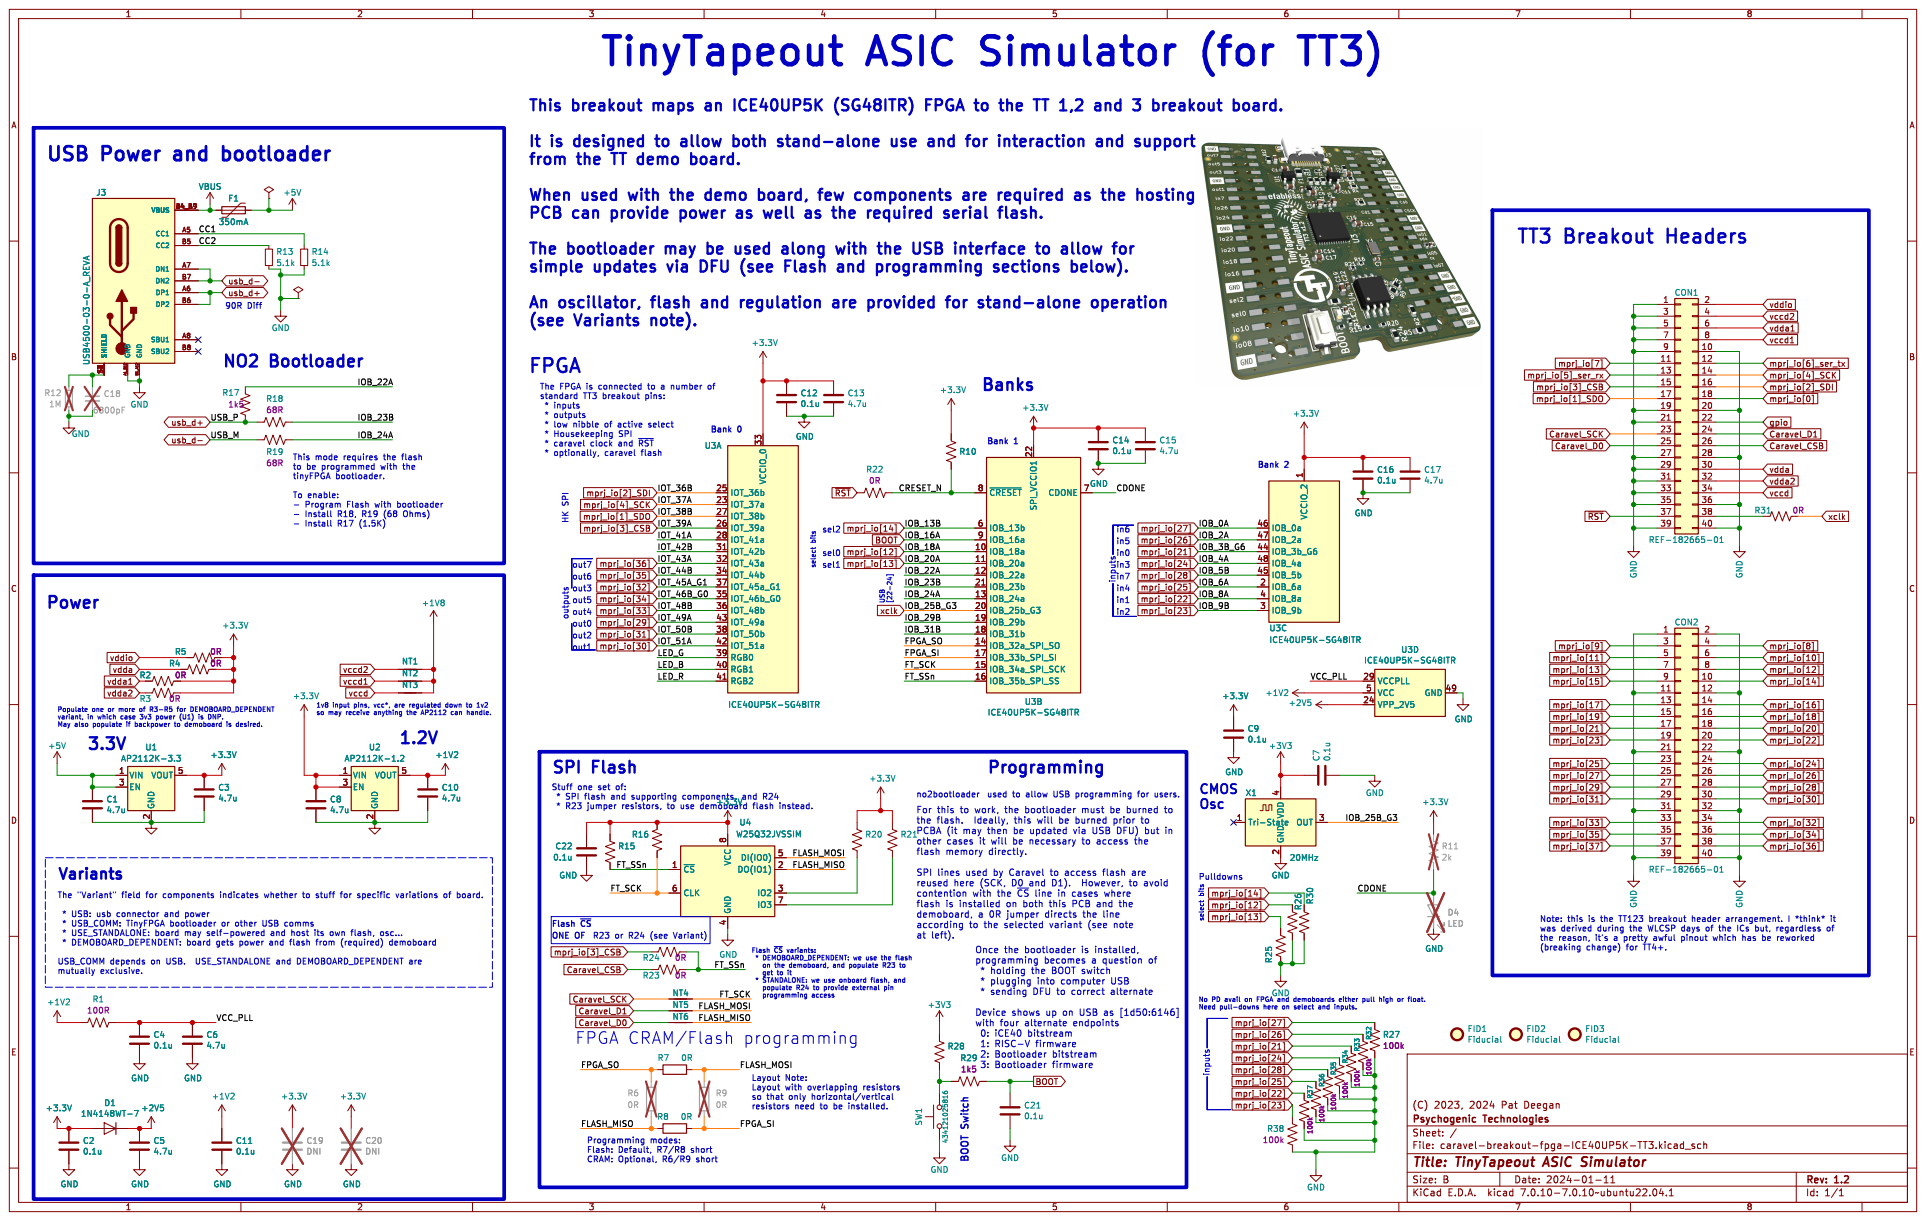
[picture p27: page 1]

out4 TinyTapeout ASIC Simulator (for TT3)

This breakout maps an ICE40UP5K (SG48ITR) FPGA to the TT 1,2 and 3 breakout board.

USB Power and bootloader

from the TT demo board.

When used with the demo board, few components are required as the hosting
PCB can provide power as well as the required serial flash.

The bootloader may be used along with the USB interface to allow for

This mode requires the flash
tinyFPGA bootloader. To enable: - Program Flash with bootloader

other cases it will be necessary to access the
flash memory directly. SPI lines used by Caravel to access flash are

the reason, it's a pretty awful pinout which has be reworked


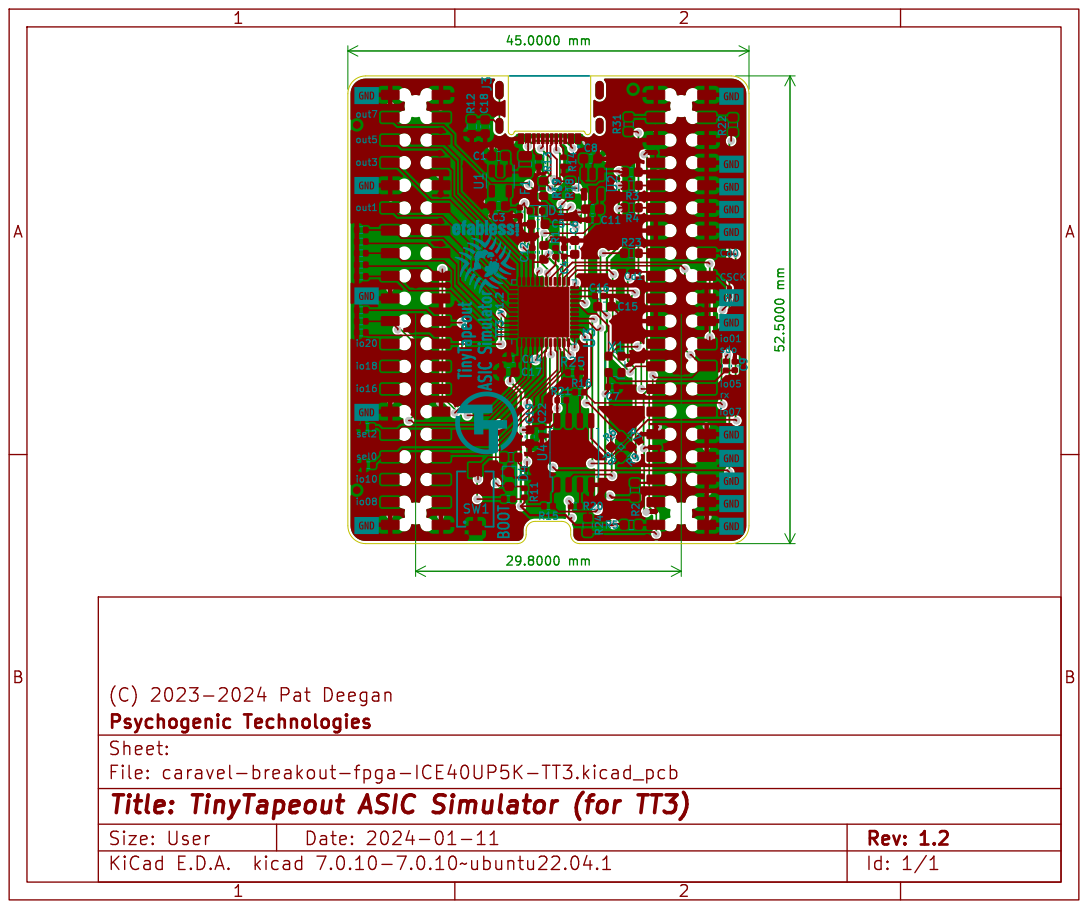
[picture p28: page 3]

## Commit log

2024-03-25 TT04 QFN breakout
    [breakout-tt4-qfn-B_Cu.gbr, breakout-tt4-qfn-B_Mask.gbr, breakout-tt4-qfn-B_Paste.gbr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]
2024-03-25 TT02/TT03 QFN breakout import
    [caravel-breakout-qfn-B_Cu.gbr, caravel-breakout-qfn-B_Mask.gbr, caravel-breakout-qfn-B_Paste.gbr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]
2024-03-25 TT3 ASIC sim board
    [caravel-breakout-fpga-ICE40UP5K-TT3-B_Cu.gbr, caravel-breakout-fpga-ICE40UP5K-TT3-B_Mask.gbr, caravel-breakout-fpga-ICE40UP5K-TT3-B_Paste.gbr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]
2024-04-11 modified silk for TT04
    [breakout-tt4-qfn-B_Cu.gbr, breakout-tt4-qfn-B_Mask.gbr, breakout-tt4-qfn-B_Paste.gbr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]
2024-04-11 tt04 dir rename
    [breakout-tt4-qfn-B_Cu.gbr, breakout-tt4-qfn-B_Mask.gbr, breakout-tt4-qfn-B_Paste.gbr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]
2024-04-11 file mv to tt04
    [breakout-tt04-qfn.kicad_pcb, breakout-tt04-qfn.kicad_sch]
2024-04-11 project rename to TT04
    [breakout-tt04-qfn.kicad_pcb, breakout-tt04-qfn.kicad_sch]
2024-04-16 TT04+ FPGA ASIC Simulator v1.0 release
    [breakout-fpga-ICE40UP5K.kicad_pcb, breakout-fpga-ICE40UP5K.kicad_sch]
2024-05-02 refactor: rename tt3 -> tt03
    [caravel-breakout-fpga-ICE40UP5K-TT3-B_Cu.gbr, caravel-breakout-fpga-ICE40UP5K-TT3-B_Mask.gbr, caravel-breakout-fpga-ICE40UP5K-TT3-B_Paste.gbr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]
2024-05-02 add TT04+ QFN socket adapter board
    [breakout-tt04-qfn-socket.kicad_pcb, breakout-tt04-qfn-socket.kicad_sch]
2024-05-22 add PIN1 marker for QFN socket board
    [breakout-tt04-qfn-socket.kicad_pcb]
2024-06-04 Final DNPs used
    [breakout-fpga-ICE40UP5K.kicad_sch]
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2024-08-12 First TT06 openframe + analog carrier
    [analog_connectors.kicad_sch, breakout-tt06-qfn.kicad_pcb, breakout-tt06-qfn.kicad_sch]
2024-11-04 CTRL MUX nReset and Increment lines crossed at chip: fixed
    [breakout-tt06-qfn.kicad_pcb, breakout-tt06-qfn.kicad_sch]
2024-11-15 feat: add TT06+ QFN socket adapter board
    [analog_connectors.kicad_sch, breakout-tt06-qfn-socket.kicad_pcb, breakout-tt06-qfn-socket.kicad_sch]
2024-11-15 fix: move capacitors outside the socket boundary
    [breakout-tt06-qfn-socket.kicad_pcb]
2024-11-15 feat: add TT logo to TT06+ socket board
    [breakout-tt06-qfn-socket.kicad_pcb]
2024-11-15 feat(tt06-qfn-socket): assign components
    [analog_connectors.kicad_sch, breakout-tt06-qfn-socket.kicad_pcb, breakout-tt06-qfn-socket.kicad_sch]
2024-11-15 chore(tt06-qfn-socket): generate production files
    [BOM-breakout-tt06-qfn-socket.csv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]
2024-11-15 fix(tt06-qfn-socket): rotate holes in socket footprint
    [breakout-tt06-qfn-socket.kicad_pcb]
2024-11-15 feat: add TT02 COB board
    [BOM-breakout-tt02-cob.csv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]
2024-11-15 fix(tt02-cob): use rounded rectangle for metal shield
    [BOM-breakout-tt02-cob.csv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]
2024-11-15 fix(tt02-cob): correct pin order + add mounting holes
    [BOM-breakout-tt02-cob.csv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]
2024-11-15 fix(tt02-cob): add ground fill keepout area around caravel chip
    [BOM-breakout-tt02-cob.csv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]
2024-11-15 fix(tt06-qfn-socket): swapped pins `c_sel_inc` & `c_rst_n`
    [breakout-tt06-qfn-socket.kicad_pcb, breakout-tt06-qfn-socket.kicad_sch]
2024-11-29 fix(tt06-qfn-socket): fix capacitor values (partially reverts 0f8ee4a2)
    [breakout-tt06-qfn-socket.kicad_pcb, breakout-tt06-qfn-socket.kicad_sch]
2024-11-29 fix(tt06-qfn-socket): mark the EEPROM as DNP
    [breakout-tt06-qfn-socket.kicad_pcb, breakout-tt06-qfn-socket.kicad_sch]
2024-11-29 fix(tt06-qfn-socket): sync "exclude from BOM" with DNP
    [breakout-tt06-qfn-socket.kicad_pcb, breakout-tt06-qfn-socket.kicad_sch]
2024-11-29 chore(tt06-qfn-socket): regenerate production files
    [BOM-breakout-tt06-qfn-socket.csv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]
2024-12-14 TT06 carrier v1.1 as in production run
    [analog_connectors.kicad_sch, breakout-tt06-qfn.kicad_pcb, breakout-tt06-qfn.kicad_sch]
2024-12-14 Carrier board v1.1 produced for TT07 run
    [analog_connectors.kicad_sch, breakout-tt07-qfn.kicad_pcb, breakout-tt07-qfn.kicad_sch]
2025-01-08 fix for mystery regression on MUX rst/sel lines
    [breakout-tt07-qfn.kicad_pcb, breakout-tt07-qfn.kicad_sch]
2025-02-24 refactor, tt02
    [breakout-tt02-cob.kicad_pcb, breakout-tt02-cob.kicad_sch]
2025-02-24 refactor, tt03
    [BOM-breakout-tt02-cob.csv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]
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2025-02-24 tt07 cleanup, prep for tt08
    [analog_connectors.kicad_sch, breakout-tt07-qfn.kicad_pcb, breakout-tt07-qfn.kicad_sch]
2025-02-25 tt08 uniform file naming refactor
    [breakout-qfn.kicad_pcb, breakout-qfn.kicad_sch]
2025-02-25 TT08 breakout and documentation refactor
    [analog_connectors.kicad_sch, breakout-qfn.kicad_pcb, breakout-qfn.kicad_sch]
2025-02-25 minor routing tweaks and stitch
    [breakout-qfn.kicad_pcb]
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2025-02-25 Fab layer cleanup and BOM MPNs
    [breakout-qfn.kicad_pcb, breakout-qfn.kicad_sch]
2025-06-25 fabricfox TT06+ FPGASIC asic simulator, initial commit
    [fpga.kicad_sch, tt06-fpga-ICE40UP5k.kicad_pcb, tt06-fpga-ICE40UP5k.kicad_sch]
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2025-07-31 LCSC components and minor layout tweaks for production run
    [fpga.kicad_sch, tt06-fpga-ICE40UP5k.kicad_pcb, tt06-fpga-ICE40UP5k.kicad_sch]
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2025-12-02 increased size of power rail jumpers
    [breakout-sky-qfn.kicad_sch]
2026-01-12 FPGA ASIC simulator: FabricFox v2 import
    [fpga.kicad_sch, ttdbv3-fpga-ICE40UP5k.kicad_pcb, ttdbv3-fpga-ICE40UP5k.kicad_sch]
2026-02-08 sky breakout layout tweaks, v3.2
    [breakout-sky-qfn.kicad_sch]
2026-02-09 IHP breakout v1.0, initial import
    [breakout-ihp-qfn.kicad_pcb, breakout-ihp-qfn.kicad_sch]
2026-02-09 IHP schem title tweak
    [breakout-ihp-qfn.kicad_sch]
2026-02-09 IHP breakout zone fill refresh
    [breakout-ihp-qfn.kicad_pcb]
2026-02-09 IHP breakout rework from feedback
    [breakout-ihp-qfn.kicad_pcb, breakout-ihp-qfn.kicad_sch]
2026-02-09 10u DNPs for IHP breakout
    [breakout-ihp-qfn.kicad_sch]
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2026-02-10 uo tweaks, DRC clean
    [breakout-ihp-qfn.kicad_pcb]
2026-02-10 schem cleanup/project mux bus renames
    [breakout-ihp-qfn.kicad_pcb, breakout-ihp-qfn.kicad_sch]
2026-02-10 PDN and other minor layout touchups
    [breakout-ihp-qfn.kicad_pcb]
2026-08-11 More better and IPCish footprint for IHP
    [breakout-ihp-qfn.kicad_pcb, breakout-ihp-qfn.kicad_sch]
2026-08-11 ihp breakout as uploaded to pcb-files
    [breakout-ihp-qfn.kicad_pcb]
2026-08-19 IHP breakout w/tnt footprint
    [breakout-ihp-qfn.kicad_pcb, breakout-ihp-qfn.kicad_sch]
2026-09-07 GF CoB DIP breakout, initial import, v0.9
    [breakout-dip-gf.kicad_pcb, breakout-dip-gf.kicad_sch]
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2026-09-19 remap/reroute of pclk and VAA to Vcore
    [breakout-dip-gf.kicad_pcb, breakout-dip-gf.kicad_sch]
2026-10-21 bonding house + gnd rework
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
